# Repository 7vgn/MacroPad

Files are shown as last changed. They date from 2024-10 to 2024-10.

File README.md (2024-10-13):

# MacroPad
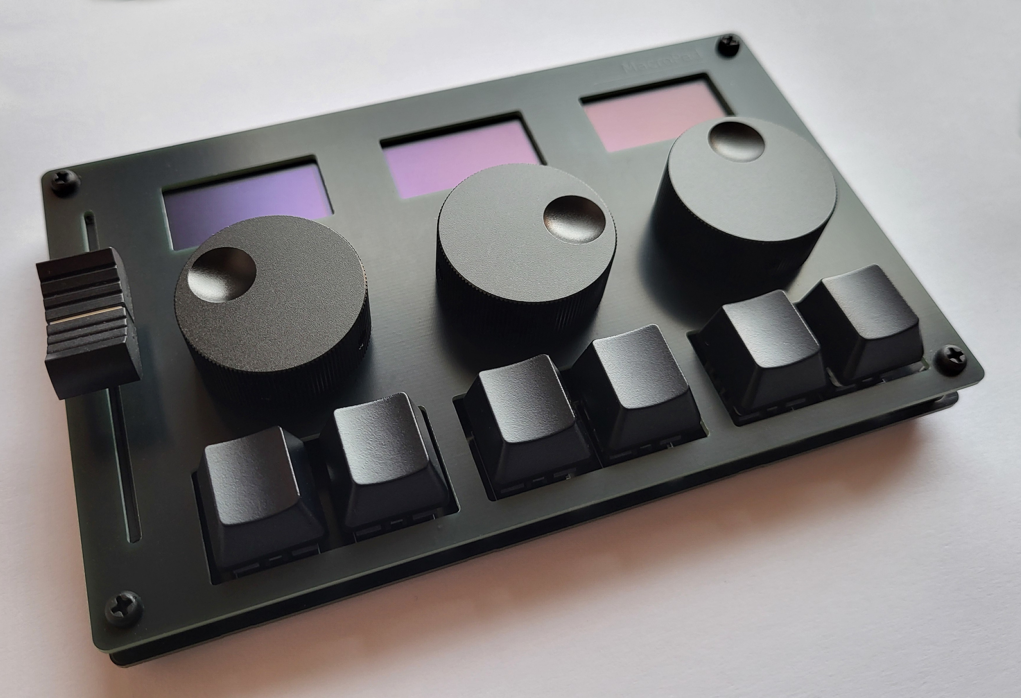
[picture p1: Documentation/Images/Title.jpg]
Title Image

> [!NOTE]
> This project is still under development. While almost everything works on Linux, Windows is a mess.

## What is This?
MacroPad is a USB input device with six keys, three rotary encoders, a slider,
and three OLED displays. All controls can be configured to send user-defined
mouse or keyboard input to the computer. Multiple profiles are supported,
allowing you to change between different key-assignments with the press of a
button. Typical applications include audio and video editing, computer graphics,
and presentations.

MacroPad implements standard USB HID (human interface) device classes and thus
requires no driver. The only is software that is needed is a [Program for
Configuring](Software/) it and potentially some [software for the slider](SliderApps/).

MacroPad is powered by a
[Raspberry Pi Pico](https://www.raspberrypi.com/documentation/microcontrollers/raspberry-pi-pico.html)
using the RP2040 microcontroller.

## How Does It Work?
When plugged into a computer, MacroPad presents itself as a three-in-one
input device composed of a keyboard, a mouse, and a miscellaneous input device.
All keys and rotary encoders can be configured to send keyboard or mouse input
to the computer.

The slider is also an HID-class device that needs no driver. However, most
operating systems don't know what to do with slider input and so they just
ignore it. For that reason, you will most likely want to have a piece of
software running that consumes these inputs and performs certain actions,
like adjusting volume or changing the brush size in a drawing application. 
You can find several examples in the [SliderApps](SliderApps/) folder.

## Can I Have One?
MacroPad is not sold anywhere. In this repository, you can find all the
necessary information and code to build a MacroPad yourself. Please have a look
at the [Building Instructions](Documentation/BuildingInstructions.pdf) and
the [User's Guide](Documentation/UsersGuide.pdf).
Building a MacroPad is not particularly difficult. As long as you can hold a
soldering iron without touching the wrong end, you should be fine.

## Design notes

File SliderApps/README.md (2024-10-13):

The slider on MacroPad acts as a standard USB HID-class slider device and thus needs no driver. However, most operating systems don't know what to do with slider input and therefore just ignore it. For the slider to have any effect, you will need some application running on the host. 

This directory contains two small libraries - one for C++ and one for Python - that can be used to write such applications. Both libraries need the [https://github.com/libusb/hidapi](HIDAPI library) to be installed. 
- The C++ library consists of the MacroPad.h and MacroPad.cpp files. An example for how to use it is in example.cpp. 
- The Python library consists of the MacroPad.py file. An example for how to use it is in example.py. The [cffi](https://cffi.readthedocs.io/) module must be installed. 

In the subdirectories you can find more practical applications for these libraries.

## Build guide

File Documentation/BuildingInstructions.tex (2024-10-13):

\documentclass{article}
\usepackage[a4paper]{geometry}
\usepackage[skip=10pt]{parskip}
\usepackage{amssymb}
\usepackage{graphicx}
\usepackage{hyperref}
\usepackage[section]{placeins}
\usepackage[official]{eurosym}
\usepackage{textgreek}
\usepackage{tcolorbox}
\usepackage{listings}
\usepackage{textcomp}
\usepackage{ccicons}
\usepackage{tikz}
\usepackage{multirow}
\usepackage{longtable}
\usepackage{wasysym}
\usepackage{nicefrac}
\usepackage{pdflscape}

\renewcommand{\familydefault}{\sfdefault}

\setlength\parindent{0pt}

\newenvironment{note}{\begin{tcolorbox}[colback=blue!5!white,colframe=blue!75!black,title=\textbf{Note}]}{\end{tcolorbox}}
\newenvironment{caution}{\begin{tcolorbox}[colback=red!5!white,colframe=red!75!black,title=\textbf{Caution}]}{\end{tcolorbox}}
\newcommand{\file}[1]{\texttt{#1}}

\lstset
{
	basicstyle=\footnotesize\ttfamily,
	breaklines=true,
	keywordstyle=\bfseries\color{green!40!black},
	commentstyle=\itshape\color{purple!40!black},
	identifierstyle=\color{blue},
	stringstyle=\color{orange},
	tabsize=4
}

\begin{document}
\hypersetup{pageanchor=false}
\begin{titlepage}
\thispagestyle{empty}
\centering
\textsf{\Huge MacroPad}\\[1cm]
\textsf{\Large Programmable USB Input Device}\\[3cm]
\\[3cm]
\textsf{\Large Building Instructions}
\end{titlepage}
\hypersetup{pageanchor=true}

\section*{License}
This document is licensed under Creative Commons \href{https://creativecommons.org/licenses/by-nc/4.0/}{Attribution-NonCommercial 4.0 International} (CC BY-NC 4.0 \ccCopy\,\ccAttribution\,\ccNonCommercial).

Attribution to \href{http://github.com/7vgn/MacroPad/}{http://github.com/7vgn/MacroPad/} is sufficient.

\tableofcontents

\section{Introduction}

\subsection{Cloning the GitHub Repository}\label{sec:gitclone}
The very first thing you should do is download (``clone'') the MacroPad GitHub repository to your computer. In order to do so, you first need to \href{https://git-scm.com/downloads}{install Git}.

Once installed, open a command prompt, navigate to the directory you want to download into, then run:
\begin{lstlisting}[language=bash]
git clone --recurse-submodules https://github.com/7vgn/MacroPad.git
\end{lstlisting}
This creates a subdirectory named \file{MacroPad} containing everything you need, including this document.
Downloading might take a few minutes since the \lstinline[language=bash]{--recurse-submodules} option also downloads other required libraries that are included as submodules. 

\subsection{How Much Does It Cost to Build One?}
Prices vary a lot over time and across countries, therefore we can't give a fixed number.
As an example, in mid 2024 in Western Europe, we were able to get the PCBs for approximately 40\euro{} and the other components for around 30\euro{}. However, this included five copies of each PCB (the minimum amount that could be ordered from the manufacturer), so the price per unit drops significantly if you build more than one.

Some components like the resistors, capacitors, slide potentiometer, and EEPROM can quite possibly be salvaged from old electronics.
You don't need the exact \textOmega{} or nF values. Anything in the rough ballpark should work just as well.

\section{Making the Hardware}
If you've never worked with electronics, building your own USB device might seem daunting. But it's actually really not that hard and we encourage you to do it! This chapter contains all the information you need. 

\subsection{Things You Need}
\subsubsection{Tools}
When it comes to tools, you need a soldering iron, pincers, wire cutters, and a well-lit and ventilated workspace. We also recommend a multimeter for testing your solder joints. 
None of these have to be of particularly high quality, normal hobbyist workshop-type tools will do. 

In terms of materials, you need some lead-free solder wire, solder wick, flux, and isopropyl alcohol for cleaning. You can make flux yourself by dissolving some \href{https://en.wikipedia.org/wiki/Rosin}{rosin} flakes in isopropyl alcohol. A clean empty nailpolish remover bottle is ideal for this, as they usually come with a small brush in the lid. 

\subsubsection{Printed Circuit Boards (PCBs)}
The main structure of MacroPad is made from two Printed Circuit Boards (PCBs). The bottom PCB carries all the electrical functions, the top just serves as the front plate. While it is easiest to have them both maufactured together, you can replace the top PCB with a 3D-printed or laser-cut front plate. 

The PCBs were designed using Version 8 of \href{https://www.kicad.org/}{KiCAD}. Once you have downloaded and installed the program, you can open the project from the \file{PCB} subdirectory. 

Find a manufacturer for your PCBs. Producing single digit quantities of PCBs is typically referred to as ``prototyping''. The most affordable PCB prototyping services are usually located in China and take up to two week for shipping. 
When shopping for PCB manufacturing services, use the following parameters:
\begin{itemize}
\item Size: 160mm by 100mm
\item Layers: 2 (there are copper traces on the front and back)
\item Thickness: 1.6mm (this is the standard thickness for PCBs)
\item Surface finish: any lead-free option (HASL is usually the cheapest)
\item Color: up to you (we use black)
\item Customer reference/order number: Manufacturers often print a reference number on the PCBs. While this is fine on the back PCB, you probably don't want that on the front plate. Most manufacturers allow omitting the number (for a fee) or printing it at a position chosen by the customer (e.g. on the back side or under the knobs). Choosing the position is sometimes done on the ordering page. Other times, you have to place a dummy label in KiCAD which the manufacturer will replace with the number. 
\end{itemize}

PCB manufacturers want the data in the shape of so-called `Gerber Files''. Gerbers are to PCBs what PDFs are to text documents. When exporting Gerbers from KiCAD, there are some options to choose. Virtually all manufacturers list those on their website. Most of the time they will provide detailed instructions and screenshots for all popular CAD programs, including KiCAD. 

As an example, here is how you would order from JLCPBC. This is just an example, we are not endorsing them or any other manufacturer! 

After loading the project in KiCAD, open \file{MacroPad.kicad\_pcb}. 

A Google search for ``jlcpcb kicad'' will guide you to \href{https://jlcpcb.com/help/article/how-to-generate-gerber-and-drill-files-in-kicad-8}{this page} with a detailed tutorial. Follow the steps, then compress the resulting files into a ZIP file. 

For the front plate, open the \file{MacroPad\_FrontPlate.kicad\_pcb} file in the PCB Editor. Before we export Gerbers, we need to add a text label for the reference number. Select the ``B.Silkscreen'' layer and place a text label with the word "JLCJLCJLCJLC" somewhere on the PCB. Make the text width and height at least 1mm and the thickness at least 0.153mm (this is the minimum font size allowed by JLCPCB). Now proceeed with the export process as before. 

Go to the JLCPCB homepage and upload the first ZIP file. The website should recognise most of the settings automatically. There are only some minor changes you need to make:
\begin{itemize}
\item Select the PCB color (the default is green)
\item Choose ``LeadFree HASL'' for the Surface Finish (ENIG works too, but is much more expensive)
\item (For the Front PCB) Under ``Mark on PCB'' select ``Order Number (Specify Position)'' (clicking the question mark icon will explain why we placed the text label earlier)
\end{itemize}

Put the PCB in the shopping cart, then repeat the process for the second ZIP file. Ultimately, it should look something like Figure \ref{fig:pcb_ordering_example}. 

\begin{figure}[htb]
\centering
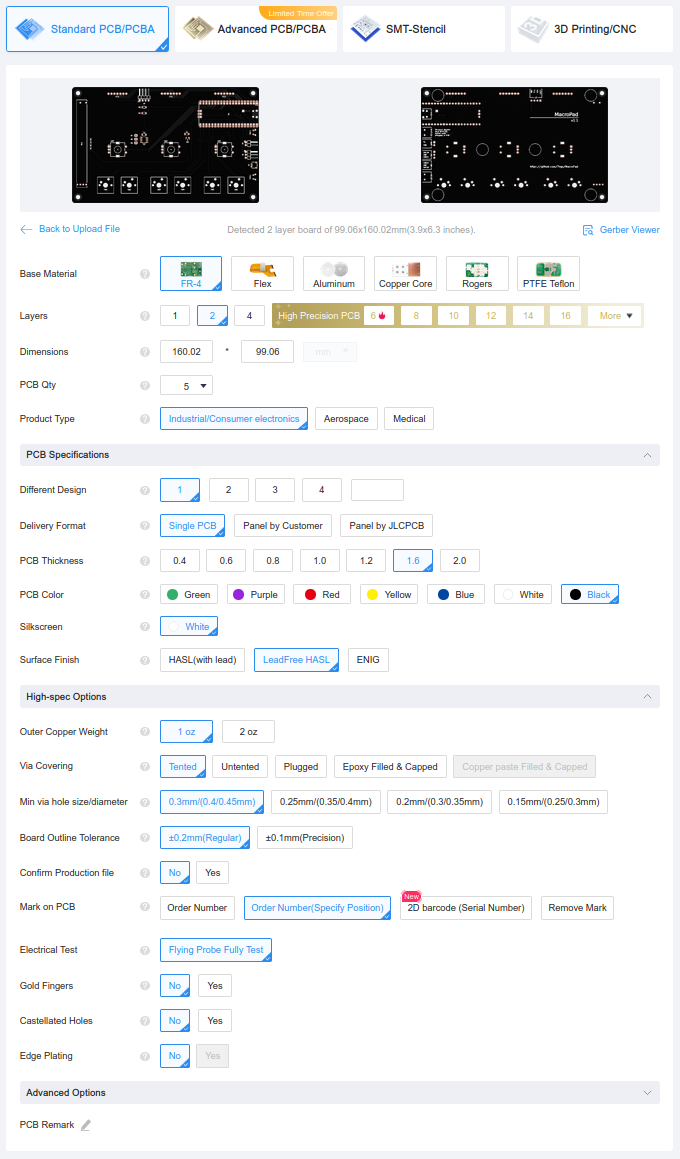
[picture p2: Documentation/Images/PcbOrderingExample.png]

\caption{Example for Ordering PCBs}
\label{fig:pcb_ordering_example}
\end{figure}

\subsubsection{Electronic (and Other) Components}
Figure \ref{fig:bom} is the Bill of Materials (BOM).
It contains product codes for a popular European, American, and Chinese retailer each. Again, this is just to give you an example and does not constitute an endorsement of those sellers. There are myriads of alternatives, many of which might be cheaper or have better availability in your country.

\begin{landscape}
\begin{figure}[htb]
\centering
\begin{longtable}{|l|l|l|c|l|l|l|}\hline
\textbf{Ref}&\textbf{Component}&\textbf{Value}&\textbf{Qty}&\textbf{reichelt.de}&\textbf{mouser.com}&\textbf{AliExpress}\cr\hline\hline
\multicolumn{7}{|c|}{\emph{Necessary Components}}\cr\hline
C2&Ceramic Capacitor&1206, 100nF&1&WAL 1206B104K500&GRM033Z71C104KE14D&\cr\hline
DS1..3&OLED Display&1.3'', SPI (7-pin), SH1106&3&&&\href{https://www.aliexpress.com/item/1005006127524245.html}{Link}\cr\hline
R1,R2&Resistor&1206, 4.7k\textOmega, $\nicefrac{1}{4}$W&2&WAL WR12X4701FTL&279-CRG1206F4K7/10&\cr\hline
\multirow{2}{*}{RV1}&Slide potentiometer&Stereo, linear, 75mm, 10k\textOmega&1&RS60112-LIN10K&688-RS60112A600N&\cr\cline{2-7}
&Knob&&1&KNOPF 4X1,2SW&&\cr\hline
\multirow{2}{*}{SW1..6}&Mechanical switch&Cherry MX Brown&6&CHERRY MX1A-G1NW&540-MX1A-G1NW&\href{https://www.aliexpress.com/item/1005005448524292.html}{Link}\cr\cline{2-7}
&Key caps&For Cherry MX, black&6&&&\href{https://www.aliexpress.com/item/1005006790237962.html}{Link}\cr\hline
\multirow{2}{*}{SW7..9}&Rotary Encoder&15mm shaft length, D-type&3&STEC12E08&858-EN11-VSM1AF15&\href{https://www.aliexpress.com/item/1005005983134515.html}{Link}\cr\cline{2-7}
&Knob&32mm, aluminium, black&3&&&\href{https://www.aliexpress.com/item/1005002272457890.html}{Link}\cr\hline
SW10&Micro switch&2x4x3.5mm, right angle&1&&&\href{https://www.aliexpress.com/item/32873390410.html}{Link}\cr\hline
U1&Raspberry Pi Pico&&1&RASP PI PICO&358-SC0915&\href{https://www.aliexpress.com/item/1005006800440665.html}{Link}\cr\hline
U2&EEPROM&24C512, 64kByte, SOP-8&1&&556-AT24C512C-SSHM-B&\cr\hline
&Rubber/Silicone Feet&Adhesive, $\diameter$11mm $\times$ 5mm&4..6&3M SJ5003 BLACK&517-SJ-5003BK&\href{https://www.aliexpress.com/item/1005005994012506.html}{Link}\cr\hline
&Stand-offs&Male/female, M3, 8mm, black&4&VT DA 8MM&710-971080365&\multirow{2}{*}{\href{https://www.aliexpress.com/item/1005006422618943.html}{Link}}\cr\cline{1-6}
&Bolts and nuts&M3, black&4&&&\cr\hline
&USB cable&Micro or type C, depending on U1&1&&&\cr\hline
\hline\multicolumn{7}{|c|}{\emph{Optional Components}}\cr\hline
C1&Ceramic Capacitor&1206, 100nF&1&WAL 1206B104K500&GRM033Z71C104KE14D&\cr\hline
J1&Pin Header&2.54mm, 1 row, 3 pins&1&SL 1X40W 2,54&538-22-28-6030&\cr\hline
J2&Connector&JST SH SM03B-SRSS-TB&1&&306-SM03BSRSSTBLFSNP&\href{https://de.aliexpress.com/item/1005006027334406.html}{Link}\cr\hline
J3&Pin Header&2.54mm, 1 row, 2 pins&1&SL 1X40W 2,54&538-22-28-6021&\cr\hline
J4&Pin Header&2.54mm, 1 row, 4 pins&1&SL 1X40W 2,54&538-22-28-6040&\cr\hline
SW11&Micro switch&2x4x3.5mm, right angle&1&&&\href{https://www.aliexpress.com/item/32873390410.html}{Link}\cr\hline
U3&Voltage reference&LM4040, 3.0V, SOT-23&1&LM 4040 CIM3-3.0&926-LM4040CIM330NOPB&\cr\hline
\end{longtable}
\caption{Bill of Materials}
\label{fig:bom}
\end{figure}
\end{landscape}

\paragraph{Necessary Components}
The OLED displays don't have a real name or product number but you'll find plenty of them for cheap on marketplaces like eBay or AliExpress. Make sure to get the SPI variant (7 pins) and not the I²C variant (4 pins).

The slide potentiometer is stereo (i.e.\ two mechanically connected potentiometers in one, typically used in audio devices) even though we're only using one. We found that the stereo ones are more widely available and often cheaper than the mono variant. We don't recommend buying the potentiometer from less reputable sources since there are massive differences in quality. 

For the Raspberry Pi Pico you can use the original one or a clone with the same form factor. The latter might differ in the quality of the flash memory and the voltage regulator, but the microcontroller itself is always the same RP2040 chip.\\
The one big advantage of clones is that they are available with a USB-C connector, whereas the original Pico only comes with Micro USB.\\
Other than some issues when flashing via SWD (see Section \ref{sec:fwflash}) -- which you don't need to do -- you won't notice any difference between the two.

\paragraph{Optional Components}
U3 and C1 can be used to stabilize the reference voltage for the Pico's analogue-to-digital converter (ADC) which reads the slide potentiometer.
Under normal circumstances this shouldn't be necessary. Note that the LM4040 will require approximately 1.5mA all the time which might violate the USB suspend current limit.

J1..4 and SW11 are useful if you want to work on the firmware but they are not required for normal operation.
J3 is a UART connector where the Pico prints debug messages.
J1 is an SWD connector for easier flashing and debugging. J2 is an alternative to J1 for use with the Raspberry Pi Debug Probe.
J4 is an I²C connector where you can monitor the traffic between the Pico and the EEPROM (or connect other I²C devices).
SW11 is the Pico's reset button.

\subsection{Soldering}
Through-hole components are the easiest to solder: just stick them into the PCB, then solder them in from the back. Make sure the soldering iron heats both the component's leg and the PCB's pad. If the solder doesn't stick to both, apply some flux. 

Surface-mount components are slightly more difficult, mostly due to their size. First, apply some flux to the pads. Heat one pad and apply a small amount of solder. Then, while heating the solder on the pad with one hand, slider the component into its place with the other. At this time, the solder joint doesn't have to be nice, its only purpose is to hold the component in its correct place. Once you've achieved that, solder the other pad(s). After that, you can re-do the first solder joint if necessary. 
If the solder bridges adjacent pins, add some flux and reheat them. If this doesn't fix it, use wick to remove surplus solder. 

The recommended order for soldering is first the small components (R1, R2, C2, U2, SW10), then the Pi Pico (U1), then the rotary encoders, switches, and slider (SW1..9, RV1). 

Make sure the EEPROM (U2) is in the correct orientation. The chip has a small indent in one corner which has to align with the marking on the PCB.\\
Try to position the Pi Pico (U1) as precisely as possible. It is important that the test pad on the back line up with the through-hole in the PCB (this connects the BOOTSEL button). Put a small amount of solder in the hole to connect it. 

After that, check all connection using the continuity test mode of your multimeter. Once the displays are soldered, many solder joints become inaccessible. 

Insert the displays loosely. Mount the front plate and turn the device upside down. Shake gently so that the displays come to lie flush against the front plate, then solder them in from the back side. 

Figure \ref{fig:assembly} shows the finished PCB. 

\begin{figure}[htb]
\centering
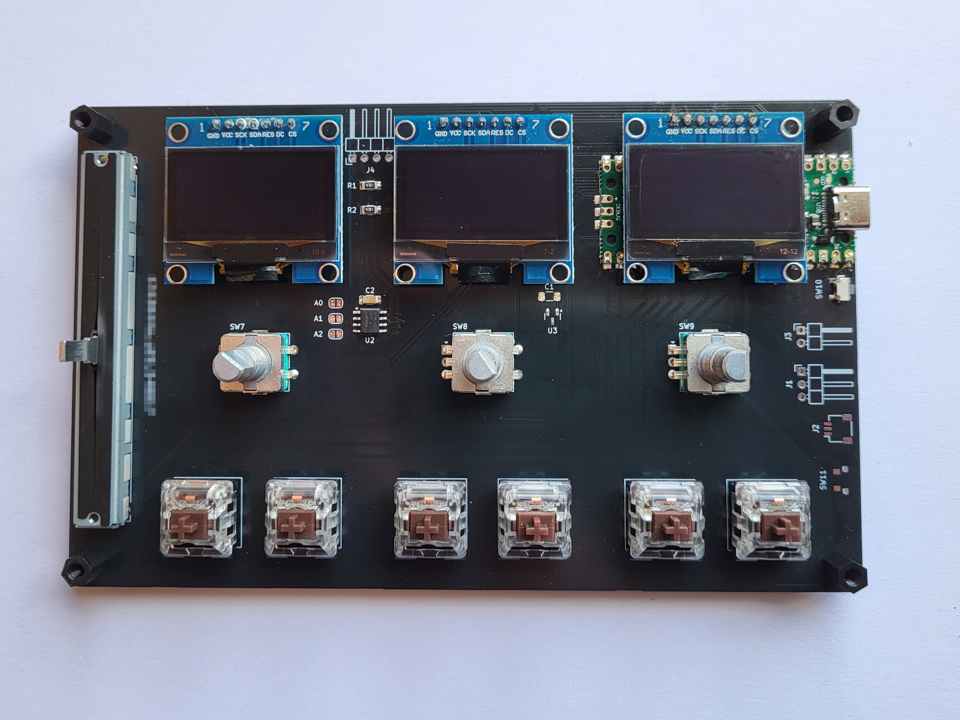
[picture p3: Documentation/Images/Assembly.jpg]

\caption{Assembly of the Back PCB}
\label{fig:assembly}
\end{figure}

Finally, put on the keycaps and knobs. When mounting the knobs onto the rotary encoders, make sure they can be pressed without touching the front plate. 

\section{Firmware}
The firmware is the code that runs on MacroPad's Raspberry Pi Pico microcontroller.

\subsection{Building the Firmware}\label{sec:fwcompile}
\begin{note}
This section is only relevant if you want to compile the firmware yourself from source code.
Otherwise you can just use the finished firmware file (\file{MacroPad.uf2}) from the GitHub repository.
\end{note}

You need to have the following tools and libraries installed:
\begin{itemize}
\item Git: You have already installed this in Section \ref{sec:gitclone}.
\item CMake: The build system used for compiling everything in this repository.
\item C++ Toolchain: Cross compiler and related tools.
\item (Optional) Doxygen: Create documentation for all the classes and functions.
\end{itemize}

If you are on a Debian-based Linux (e.g.\ Ubuntu), you can just install everything with the following command:
\begin{lstlisting}[language=bash]
sudo apt-get install git cmake gcc-arm-none-eabi libnewlib-arm-none-eabi build-essential g++ libstdc++-arm-none-eabi-newlib doxygen
\end{lstlisting}

Open a terminal and change into the \file{Firmware} subdirectory of the downloaded repository. Create a folder named build and change into it:
\begin{lstlisting}[language=bash]
mkdir build
cd build
\end{lstlisting}
Run CMake, then make:
\begin{lstlisting}[language=bash]
cmake ..
make
\end{lstlisting}
After that, you can find the MacroPad.uf2 firmware file inside the build folder.

\subsection{Flashing the Firmware}\label{sec:fwflash}
This section explains how to flash the compiled firmware onto the device via SWD using the \href{https://www.raspberrypi.com/documentation/microcontrollers/debug-probe.html}{Raspberry Pi Debug Probe}.

\begin{note}
Unless you need to flash very often (e.g.\ during debugging), USB is the easier way to go.
Please refer to the User's Guide for how to flash the firmware onto the device via USB.
\end{note}

\subsubsection{Connecting the Debug Probe}
On the Debug Probe, use the connector labelled ``D''. The probe comes with a JST-to-JST as well as a JST-to-female cable. You can use either, depending on which one of connectors J1 and J2 you've soldered. In case of J1, the orange wire goes into SWCLK, the black wire into GND, and the yellow wire into SWDIO.

If you're connecting via J2, you can use the JST-to-female cable instead to hook up MacroPad's UART debug output to the probe's ``U'' connector. The black wire goes to GND and the yellow wire to TX.
The UART settings are 115200 baud, 8N1, and flow control enabled. 

\subsubsection{OpenOCD}
Download and install \href{https://openocd.org/}{OpenOCD} from the website or via your system's package manager. 

The command for flashing is included in the \file{CMakeLists.txt} file. All you need to do is run \lstinline[language=bash]{make flash} from the \file{build} directory. 

\begin{note}
For some reason, OpenOCD does not fully reset both cores of the Pico after flashing. You have to manually press the reset button or disconnect and reconnect the USB cable.
\end{note}

\subsubsection{Pi Pico Clones with Different Flash Chips}
Many clones of the Pi Pico come with different (probably cheaper) on-board flash chips than the original.
While OpenOCD is usually capable of flashing onto these chips, it uses an internal white list which your flash might not be on.
In this case, you will see an error that looks something like this:
\begin{lstlisting}[language=bash]
Error: Unknown flash device (ID 0x00184068)
\end{lstlisting}

Note down the ID from the error message, then perform the following steps to create a patched version of OpenOCD\footnote{Thanks to \href{https://forums.raspberrypi.com/viewtopic.php?t=359245}{this forum thread} for the idea.}:
\begin{enumerate}
\item Uninstall a previously installed OpenOCD.
\item Download the code from the OpenOCD GitHub repository, then change into the directory:
\begin{lstlisting}[language=bash]
git clone https://github.com/raspberrypi/openocd.git --branch rp2040-v0.12.0 --depth=1
cd openocd
\end{lstlisting}
\item Edit src/flash/nor/spi.c and add an entry to the \lstinline[language=C]{flash_devices[]} array, for example:
\begin{lstlisting}[language=C]
FLASH_ID("Unknown", 0x03, 0xeb, 0x02, 0xd8, 0xc7, 0x00184068, 0x100, 0x10000, 0x1000000),
\end{lstlisting}
Most of the values you can just copy from existing entries, but two are important:
In the seventh column, enter the device ID that you noted down earlier.
In the last column, enter the flash size in bytes (e.g.\ 16 megabytes is $2^{24}$ bytes which is 0x1000000 in hexadecimal).
\item Compile and install the modified OpenOCD:
\begin{lstlisting}[language=bash]
./bootstrap
./configure
make
sudo make install
\end{lstlisting}
\end{enumerate}

\iffalse
# How to create the new entry:
# This forum post mentions the technique and gives an exampe for a specific (but
# different) flash chip: https://forums.raspberrypi.com/viewtopic.php?t=359245
# FLASH_ID("pu p32q32", 0x03, 0xeb, 0x02, 0xd8, 0xc7, 0x00156085, 0x100, 0x10000, 0x400000),
#
# The RP2040 datasheet puts pretty strict limits on the kinds of flash chips it
# can use as program memory. This suggests that the parameters should be pretty
# much the same as those of supported chips that are found on the original Pico.
# So far, taking the entry above and only changing the device id (7th column)
# and the size in bytes (last column) has worked.
\fi

\section{Settings App}
MacroPad comes with an application that allows you to change the settings. This application is available for Linux and Windows. You can download it from the GitHub repository.

\begin{note}
The app will probably also compile for Mac, but this has not been tested.
\end{note}

It is also possible to compile the app yourself from source code. Two libraries are required: \href{https://github.com/libusb/hidapi}{HIDAPI} (for communication via USB) and \href{https://www.wxwidgets.org/}{wxWidgets} (for the graphical user interface). You also need CMake and a C++ compiler, both of which you have already install in Section \ref{sec:fwcompile}. 

\subsection{Building on Linux}
Install the necessary libraries:
\begin{lstlisting}[language=bash]
sudo apt-get install libwsgtk3.2-dev libhidapi-dev
\end{lstlisting}

In a terminal, go to the \file{Software} subdirectory of the downloaded repository, then run: 
\begin{lstlisting}[language=bash]
mkdir build
cd build
cmake ..
make
\end{lstlisting}

After that, you will find the executables called \file{MacroPad} and \file{macropad-cli} in the \file{build} directory. 

\subsection{Building on Windows}
TODO

\section{Miscellaneous}
\subsection{USB Vendor ID and Product ID}
USB devices need a Vendor ID (VID) and Product ID (PID) to be identified by the host. VIDs and PIDs are 4-digit hexadecimal numbers. Commercial manufacturers licence their VID from the \href{https://www.usb.org/getting-vendor-id}{USB Implementers Forum (USB-IF)}.
As a hobbyist project, MacroPad does not have a VID or PID. However, for private use, no one prevents you from just using a made-up VID/PID combination (ideally one that is not used by another device).
You can specify the VID/PID in the usb\_descriptors.h file. After doing so, you need to recompile both the firmware and the Settings App.

\subsection{Key Rollover}
Key rollover describes the ability of a keyboard to register (and report to the host) multiple keys being held down at the same time. Pretty much all USB keyboards support at least 6-key rollover (6KRO). Higher-end ones even allow arbitrarily high $n$-key rollover (NKRO). Modifier keys (shift, control, alt, windows) typically do not count towards the KRO number.

There is a common misconception that USB keyboards are limited to 6KRO. This is false, albeit with a kernel of truth: USB HID\footnote{Human Interface Device}-class devices send data to the host (the computer) at regular intervals in data packages called ``reports''. The format of these reports (and as a consequence the maximum possible number of concurrently pressed keys) is not fixed. Instead, each device specifies the exact format via a ``report descriptor''. While this allows for incredible flexibility, it also makes HID drivers on the host side (those usually come with the operating system) quite complex: The driver has to read the report descriptor and from it generate a bespoke parser for each device. Not all systems have the ressources to do that. In particular, older BIOSes tend not to implement a full USB HID driver. For this reason, a special type of USB HID device was defined. These so called ``boot-protocol keyboards'' have a fixed report descriptor which only allows 6KRO.

On the hardware level, MacroPad has no limitations regarding key rollover. All input controls are wired separately to the microcontroller, thanks to the relatively low number of switches and knobs. There is no matrix involved which makes eliminates any kind of ghosting.

On the software side, things become more interesting. Keep in mind that MacroPad is not a standard keyboard where each switch corresponds to one key being sent to the host. Instead, all input controls are freely programmable. In theory, you could configure a switch to act as if the whole alphabet had been pressed. In other words, the number of physical keys has nothing to do with how many keys are reported to the host.
MacroPad is capable of emulating a boot-protocol keyboard (with 6KRO) but it can also use the normal report protocol, in which case it has 16KRO by default. It is the host that chooses which protocol to use.

While the boot protocol's 6KRO is fixed, the 16KRO can be changed if you need higher rollover: When compiling the firmware, you can pass a flag setting a specific KRO value, for example:
\begin{lstlisting}[language=bash]
cmake -DKRO=20 ..
\end{lstlisting}
Note that higher values result in longer reports, eating more of the USB connection's bandwidth. Do not go beyond 60 otherwise you risk exceeding the size of a USB package. 

\end{document}

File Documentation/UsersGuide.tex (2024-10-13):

\documentclass{article}
\usepackage[a4paper]{geometry}
\usepackage[skip=10pt]{parskip}
\usepackage{amssymb}
\usepackage{graphicx}
\usepackage{hyperref}
\usepackage[section]{placeins}
\usepackage[official]{eurosym}
\usepackage{textgreek}
\usepackage{tcolorbox}
\usepackage{listings}
\usepackage{textcomp}
\usepackage{ccicons}
\usepackage{tikz}

\renewcommand{\familydefault}{\sfdefault}

\setlength\parindent{0pt}

\newenvironment{note}{\begin{tcolorbox}[colback=blue!5!white,colframe=blue!75!black,title=\textbf{Note}]}{\end{tcolorbox}}
\newenvironment{caution}{\begin{tcolorbox}[colback=red!5!white,colframe=red!75!black,title=\textbf{Caution}]}{\end{tcolorbox}}
\newcommand{\file}[1]{\texttt{#1}}

\lstset
{
	basicstyle=\footnotesize\ttfamily,
	breaklines=true,
	keywordstyle=\bfseries\color{green!40!black},
	commentstyle=\itshape\color{purple!40!black},
	identifierstyle=\color{blue},
	stringstyle=\color{orange},
	tabsize=4
}

\begin{document}
\hypersetup{pageanchor=false}
\begin{titlepage}
\thispagestyle{empty}
\centering
\textsf{\Huge MacroPad}\\[1cm]
\textsf{\Large Programmable USB Input Device}\\[3cm]
\\[3cm]
\textsf{\Large User's Guide}
\end{titlepage}
\hypersetup{pageanchor=true}

\section*{License}
This document is licensed under Creative Commons \href{https://creativecommons.org/licenses/by-nc/4.0/}{Attribution-NonCommercial 4.0 International} (CC BY-NC 4.0 \ccCopy\,\ccAttribution\,\ccNonCommercial).

Attribution to \href{http://github.com/7vgn/MacroPad/}{http://github.com/7vgn/MacroPad/} is sufficient.
\tableofcontents

\section{Introduction}
MacroPad is a USB input device with three knobs, one slider, and six keys. It also features three OLED displays to show the current bindings of the input controls. Figure \ref{fig:overview} shows the positions of all the controls.
\begin{figure}[htb]
\centering
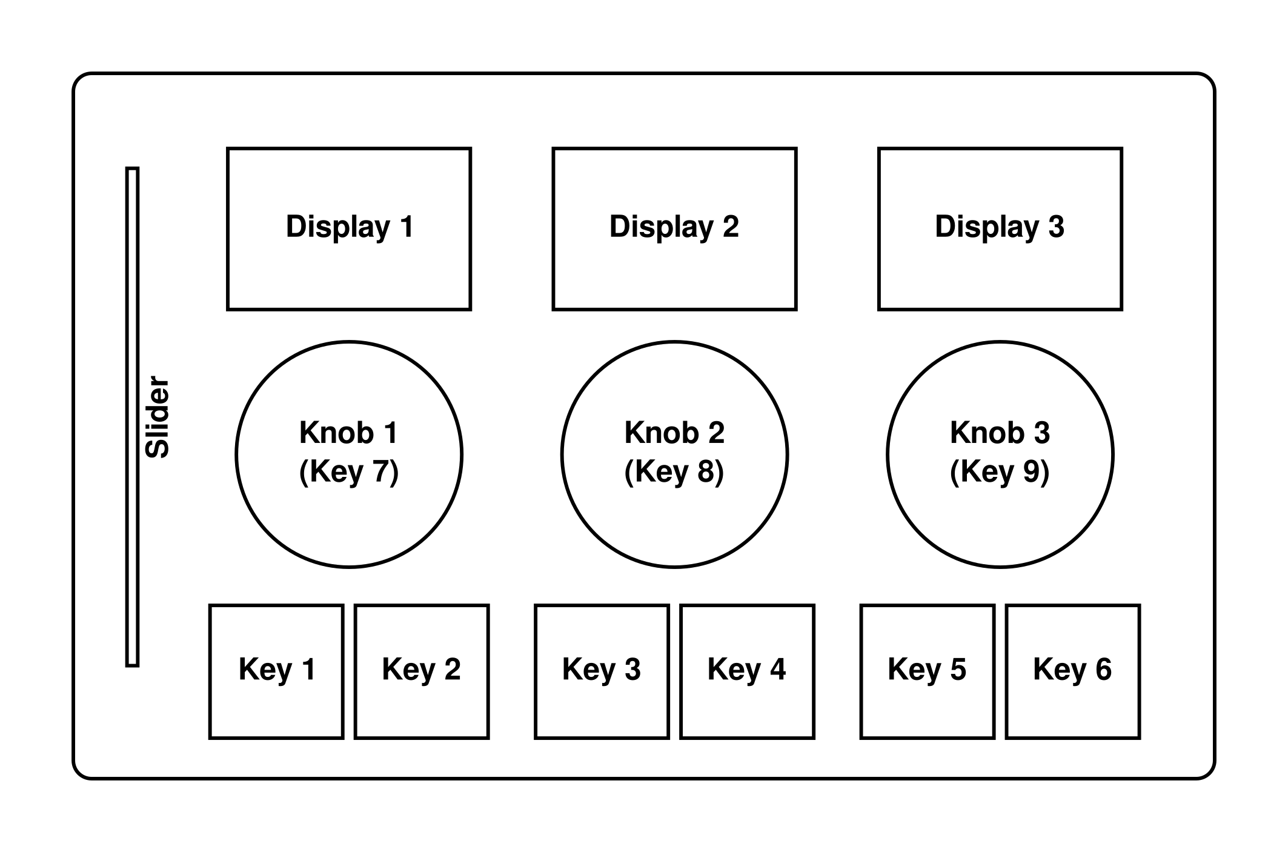
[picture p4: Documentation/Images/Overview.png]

\caption{Overview of the Device}
\label{fig:overview}
\end{figure}

The knobs can not just be turned but also pressed which is why they are also listed as keys.

During normal operation, Display 1 will show the bindings of the input controls below it, that is Keys 1 and 2, as well as Knob 1 (including Key 7). The same goes for the other two displays.

MacroPad presents itself to the computer as a combination of standard USB input devices (a keyboard, a mouse etc.). This means it should work on any operating system without the need for a driver.\\
Additional software might be required if you want it to perform actions that go beyond what keyboard/mouse/etc.\ inputs can do (for example performing actions in specific applications that don't have hotkeys).

\section{Customise MacroPad}\label{sec:customise}
\subsection{How Settings Work: Actions, Macros, and Profiles}\label{sec:settings}
MacroPad supports multiple profiles that you can switch between. The active profile defines what is sent to the computer in reaction to the user interacting with the input controls. Profiles also define the images shown on the displays and a few other things.

Having multiple profiles allows you to reconfigure MacroPad quickly without having to upload new settings. For example, you might want to create different profiles for different applications, although they are not necessarily tied to that. You might have multiple profiles for the same application or simple just one profile for everything.

To understand how a profile maps user inputs to signals sent over USB, we need to define some terms:

An \emph{Action} is a piece of information (e.g.\ ``ctrl key and right mouse button are pressed'') sent to the host over USB. Being a USB HID\footnote{Human Interface Device}-class device, MacroPad sends a report every 10 milliseconds. Such a report contains a list of all the keys and mouse buttons that are currently down, as well as incremental changes (e.g.\ how far has the mouse moved in x direction since the last report). MacroPad combines all current actions (from the different input controls) into a report which it then sends to the host.

A \emph{Macro} is a sequence of actions, with a duration for each action. A macro might for example look like this: Have the left mouse button and the shift key down (first action) for 20ms. Then move the mouse downwards at a rate of five units per 10ms (second action) for 30ms. After that, have the alt and enter keys down (third action) for 10ms.
Executing this macro would take 60ms during which time seven reports would be sent (the seventh report being ``all keys have been released'').

There are two types of user input events: First, we have keys being held down, i.e.\ events that occur over a period of time. Such an event causes an action to be continuously reported as long as the key is down.
The second type of event concerns singular points in time: This includes button presses and releases, as well as rotating a knob one notch to the left or right. These kinds of events trigger macros.

There is no dedicated key for switching between profiles. Instead, profile switching is just a special kind of action. This means you can assign it freely to any key or knob event in each profile. Or not -- if you're only using a single profile -- thus gaining more space for other actions.

\subsection{The MacroPad Settings App}\label{sec:settings_app}
MacroPad comes with an graphical user interface app that allows you to create, modify, and upload settings. You can also store settings in an XML file on your computer.

The Settings App is called \lstinline[language=bash]{MacroPad} (\lstinline[language=bash]{MacroPad.exe} on Windows). There is no installer -- just copy the executable file to some place on your computer and run it.

The Settings App should be pretty self-explanatory. Each profile is configured in a separate tab. In order to change the behaviour of an input control (like a key), click on it, then edit the macro or action. You can create or import custom pictures for each profile, key, and knob.
If you're using multiple profiles, don't forget to configure one of the input controls to switch between them.

If you're overwhelmed by the options, you can load and modify an existing settings file instead.

Once you have created your personalised settings, it is recommended that you save them in a file for safekeeping.
In order to write them to the device, hit the ``Scan for Devices'' button, choose the correct MacroPad device from the drop-down (in case you have multiple), then hit ``Write to Device''. After a few seconds, your MacroPad should have its new settings.
\begin{note}
Do not unplug the device while settings are transferred.
\end{note}

\subsubsection{User priviledges on Linux}\label{sec:linux_priviledges}
On Linux, the app must be run with root proviledges (``sudo'') since normal users are not allowed to access USB devices.

If you don't want that, you can add an exception for MacroPad: The following steps describe how to do this on Debian-based distributions like Ubuntu. On other Linux systems there might be slight differences.
\begin{enumerate}
\item Open a terminal and run \lstinline[language=bash]{lsusb}.
If lsusb is not on your system you can get it by installing the usbutils package:
\begin{lstlisting}[language=bash]
sudo apt-get install usbutils
\end{lstlisting}
Find the line with the MacroPad device and note down the Vendor ID (VID) and Product ID (PID). These are 4-letter/digit codes separated by a colon (VID:PID).\\
\item In a text editor of your choice, create a file named ``69-MacroPad.rules'' with the following content:\\
~\\
\texttt{SUBSYSTEMS=="usb", ATTRS{idVendor}=="VID", ATTRS{idProduct}=="PID", TAG+="uaccess"
KERNEL=="hidraw", ATTRS{idVendor}=="VID", ATTRS{idProduct}=="PID", TAG+="uaccess"}
~\\
Replace ``VID'' and ``PID'' with the IDs noted down before.
\item Copy the file to /etc/udev/rules.d/ (you must use root priviledges to do that):
\begin{lstlisting}[language=bash]
sudo cp 69-MacroPad.rules /etc/udev/rules.d/.
\end{lstlisting}
\item Restart your computer or run the following commands:
\begin{lstlisting}[language=bash]
sudo udevadm control --reload-rules
sudo udevadm trigger
\end{lstlisting}
\end{enumerate}

\subsection{The Command Line Settings Tool}\label{sec:cmdline_tool}
There is a command line-based alternative for the Settings App, called \lstinline[language=bash]{macropad-cli}. It can transfer the same XML settings files from and to MacroPad devices as the graphical Settings App. For more information on how to use the command-line tool, run:
\begin{lstlisting}[language=bash]
macropad-cli --help
\end{lstlisting}
The command-line tool provides no means for creating and editing settings files. For this, you need either the graphical Settings App or edit the XML file by hand.
Unless you have a very particular use case, we recommend you use the graphical Settings App instead.

\section{Firmware Update}\label{sec:firmwareupdate}
\begin{note}
Sections \ref{sec:flash} and \ref{sec:restoresettings} also apply to the initial flashing of the firmware onto an empty device.
\end{note}

\subsection{Save Your Settings}\label{sec:savesettings}
Firmware updates do not preserve the settings. If you want to keep your profiles, read them from the device and store them in a file on your computer before starting the firmware update process. See Section \ref{sec:settings_app} for details.
Make sure to use the old Settings App to do this. The Settings App can only read settings from a device with the same firmware version.

\subsection{Flash the New Firmware}\label{sec:flash}
Download the new firmware. It comes in a file ending in ``.uf2''.
\begin{enumerate}
\item Unplug your device.
\item Locate the ``BOOTSEL'' button. The labels on the back of device can help you find it.
\item Press the button and keep holding it, while plugging the USB cable from your computer into the device.
\item Your computer should recognize it as a mass storage device. On most operating systems, a file manager window will pop up.
\item Release the button.
\item Copy the new firmware file onto the device.
\item The mass storage device will immediately self-eject and MacroPad reappears as several input devices. If it doesn't, unplug and replug the USB cable.
\end{enumerate}

\subsection{Restore Your Settings}\label{sec:restoresettings}
Now you can write your settings back onto the device as described in Section \ref{sec:settings_app}.
Make sure to use the new Settings App to do this. The Settings App can only write settings to a device with the same firmware version.

\end{document}

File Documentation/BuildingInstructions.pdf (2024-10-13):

# MacroPad

## Programmable USB Input Device


## Building Instructions

## License

This document is licensed under Creative Commons Attribution-NonCommercial 4.0 International (https://creativecommons.org/licenses/by-nc/4.0/) (CC BY-NC 4.0 © b n).

Attribution to http://github.com/7vgn/MacroPad/ is sufficient.

## Contents

1 Introduction | 1
2 Making the Hardware | 2
3 Firmware | 7
4 Settings App | 10
5 Miscellaneous | 10

## 1 Introduction

### 1.1 Cloning the GitHub Repository

The very first thing you should do is download (“clone”) the MacroPad GitHub repository to your computer. In order to do so, you first need to install Git. (https://git-scm.com/downloads)

Once installed, open a command prompt, navigate to the directory you want to download into, then run:

git clone --recurse - submodules https :// github . com /7 vgn / MacroPad . git

This creates a subdirectory named MacroPad containing everything you need, including this document. Downloading might take a few minutes since the --recurse-submodules option also downloads other required libraries that are included as submodules.

1

### 1.2 How Much Does It Cost to Build One?

Prices vary a lot over time and across countries, therefore we can’t give a fixed number. As an example, in mid 2024 in Western Europe, we were able to get the PCBs for approximately 40€ and the other components for around 30€. However, this included five copies of each PCB (the minimum amount that could be ordered from the manufacturer), so the price per unit drops significantly if you build more than one.

Some components like the resistors, capacitors, slide potentiometer, and EEPROM can quite possibly be salvaged from old electronics. You don’t need the exact Ω or nF values. Anything in the rough ballpark should work just as well.

## 2 Making the Hardware

If you’ve never worked with electronics, building your own USB device might seem daunting. But it’s actually really not that hard and we encourage you to do it! This chapter contains all the information you need.

### 2.1 Things You Need

### 2.1.1 Tools

When it comes to tools, you need a soldering iron, pincers, wire cutters, and a well-lit and ventilated workspace. We also recommend a multimeter for testing your solder joints. None of these have to be of particularly high quality, normal hobbyist workshop-type tools will do.

In terms of materials, you need some lead-free solder wire, solder wick, flux, and isopropyl alcohol for cleaning. You can make flux yourself by dissolving some rosin (https://en.wikipedia.org/wiki/Rosin) flakes in isopropyl alcohol. A clean empty nailpolish remover bottle is ideal for this, as they usually come with a small brush in the lid.

### 2.1.2 Printed Circuit Boards (PCBs)

The main structure of MacroPad is made from two Printed Circuit Boards (PCBs). The bottom PCB carries all the electrical functions, the top just serves as the front plate. While it is easiest to have them both maufactured together, you can replace the top PCB with a 3D-printed or laser-cut front plate.

The PCBs were designed using Version 8 of KiCAD. (https://www.kicad.org/) Once you have downloaded and installed the program, you can open the project from the PCB subdirectory.

Find a manufacturer for your PCBs. Producing single digit quantities of PCBs is typically referred to as “prototyping”. The most affordable PCB prototyping services are usually located in China and take up to two week for shipping. When shopping for PCB manufacturing services, use the following parameters:

- Size: 160mm by 100mm
- Layers: 2 (there are copper traces on the front and back)
- Thickness: 1.6mm (this is the standard thickness for PCBs)

2

- Surface finish: any lead-free option (HASL is usually the cheapest)
- Color: up to you (we use black)
- Customer reference/order number: Manufacturers often print a reference number on the PCBs. While this is fine on the back PCB, you probably don’t want that on the front plate. Most manufacturers allow omitting the number (for a fee) or printing it at a position chosen by the customer (e.g. on the back side or under the knobs). Choosing the position is sometimes done on the ordering page. Other times, you have to place a dummy label in KiCAD which the manufacturer will replace with the number.

PCB manufacturers want the data in the shape of so-called ‘Gerber Files”. Gerbers are to PCBs what PDFs are to text documents. When exporting Gerbers from KiCAD, there are some options to choose. Virtually all manufacturers list those on their website. Most of the time they will provide detailed instructions and screenshots for all popular CAD programs, including KiCAD.

As an example, here is how you would order from JLCPBC. This is just an example, we are not endorsing them or any other manufacturer!

After loading the project in KiCAD, open MacroPad.kicad pcb.

A Google search for “jlcpcb kicad” will guide you to this page (https://jlcpcb.com/help/article/how-to-generate-gerber-and-drill-files-in-kicad-8) with a detailed tutorial. Follow the steps, then compress the resulting files into a ZIP file.

For the front plate, open the MacroPad FrontPlate.kicad pcb file in the PCB Editor. Before we export Gerbers, we need to add a text label for the reference number. Select the “B.Silkscreen” layer and place a text label with the word ”JLCJLCJLCJLC” somewhere on the PCB. Make the text width and height at least 1mm and the thickness at least 0.153mm (this is the minimum font size allowed by JLCPCB). Now proceeed with the export process as before.

Go to the JLCPCB homepage and upload the first ZIP file. The website should recognise most of the settings automatically. There are only some minor changes you need to make:

- Select the PCB color (the default is green)
- Choose “LeadFree HASL” for the Surface Finish (ENIG works too, but is much more expensive)
- (For the Front PCB) Under “Mark on PCB” select “Order Number (Specify Position)” (clicking the question mark icon will explain why we placed the text label earlier)

Put the PCB in the shopping cart, then repeat the process for the second ZIP file. Ultimately, it should look something like Figure 1.

### 2.1.3 Electronic (and Other) Components

Figure 2 is the Bill of Materials (BOM). It contains product codes for a popular European, American, and Chinese retailer each. Again, this is just to give you an example and does not constitute an endorsement of those sellers. There are myriads of alternatives, many of which might be cheaper or have better availability in your country.

3

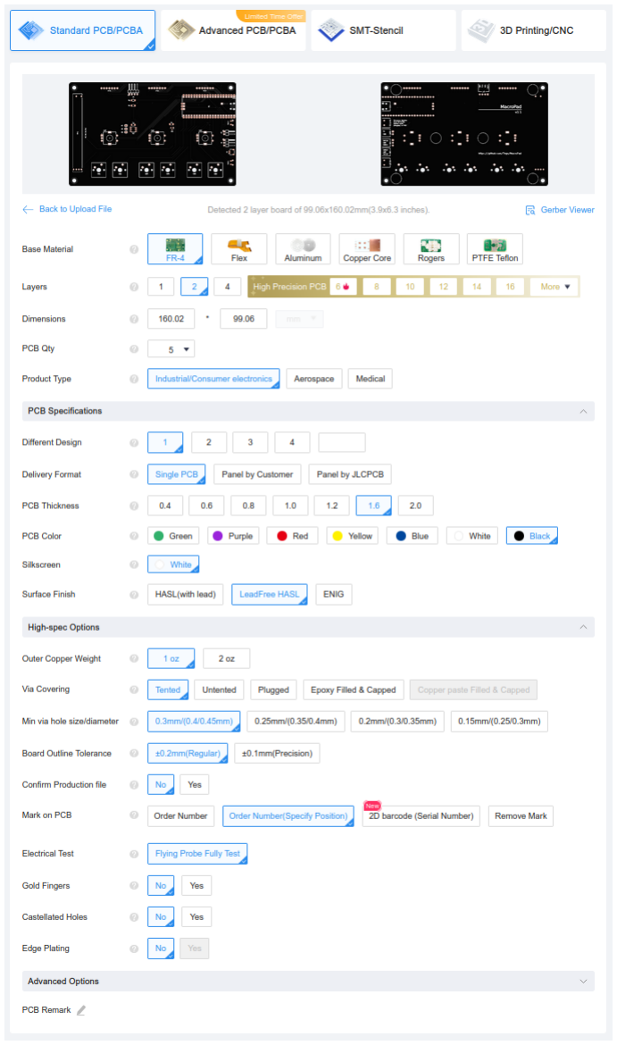
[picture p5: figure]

Figure 1: Example for Ordering PCBs

4

Ref | Component | Value | Qty | reichelt.de | mouser.com | AliExpress
Necessary Components
C2 | Ceramic Capacitor | 1206, 100nF | 1 | WAL 1206B104K500 | GRM033Z71C104KE14D
DS1..3 | OLED Display | 1.3”, SPI (7-pin), SH1106 | 3 | | | Link (https://www.aliexpress.com/item/1005006127524245.html)
R1,R2 | Resistor | 1206, 4.7kΩ, 1/4W | 2 | WAL WR12X4701FTL | 279-CRG1206F4K7/10
RV1 | Slide potentiometer | Stereo, linear, 75mm, 10kΩ | 1 1 | RS60112-LIN10K KNOPF 4X1,2SW | 688-RS60112A600N Knob
SW1..6 | Mechanical switch | Cherry MX Brown For Cherry MX, black | 6 6 | CHERRY MX1A-G1NW | 540-MX1A-G1NW | Link (https://www.aliexpress.com/item/1005005448524292.html) Key caps Link (https://www.aliexpress.com/item/1005006790237962.html)
SW7..9 | Rotary Encoder | 15mm shaft length, D-type 32mm, aluminium, black | 3 3 | STEC12E08 | 858-EN11-VSM1AF15 | Link (https://www.aliexpress.com/item/1005005983134515.html) Knob Link (https://www.aliexpress.com/item/1005002272457890.html)
SW10 | Micro switch | 2x4x3.5mm, right angle | 1 | | | Link (https://www.aliexpress.com/item/32873390410.html)
U1 | Raspberry Pi Pico | | 1 | RASP PI PICO | 358-SC0915 | Link (https://www.aliexpress.com/item/1005006800440665.html)
U2 | EEPROM | 24C512, 64kByte, SOP-8 | 1 | | 556-AT24C512C-SSHM-B
| Rubber/Silicone Feet | Adhesive, 11mm × 5mm | 4..6 | 3M SJ5003 BLACK | 517-SJ-5003BK | Link (https://www.aliexpress.com/item/1005005994012506.html)
Stand-offs | Male/female, M3, 8mm, black M3, black | 4 4 | VT DA 8MM | 710-971080365 | Link (https://www.aliexpress.com/item/1005006422618943.html) Bolts and nuts
USB cable | Micro or type C, depending on U1 | 1
Optional Components
C1 | Ceramic Capacitor | 1206, 100nF | 1 | WAL 1206B104K500 | GRM033Z71C104KE14D
J1 | Pin Header | 2.54mm, 1 row, 3 pins | 1 | SL 1X40W 2,54 | 538-22-28-6030
J2 | Connector | JST SH SM03B-SRSS-TB | 1 | | 306-SM03BSRSSTBLFSNP | Link (https://de.aliexpress.com/item/1005006027334406.html)
J3 | Pin Header | 2.54mm, 1 row, 2 pins | 1 | SL 1X40W 2,54 | 538-22-28-6021
J4 | Pin Header | 2.54mm, 1 row, 4 pins | 1 | SL 1X40W 2,54 | 538-22-28-6040
SW11 | Micro switch | 2x4x3.5mm, right angle | 1 | | | Link (https://www.aliexpress.com/item/32873390410.html)
U3 | Voltage reference | LM4040, 3.0V, SOT-23 | 1 | LM 4040 CIM3-3.0 | 926-LM4040CIM330NOPB

Figure 2: Bill of Materials

5

Necessary Components The OLED displays don’t have a real name or product number but you’ll find plenty of them for cheap on marketplaces like eBay or AliExpress. Make sure to get the SPI variant (7 pins) and not the I²C variant (4 pins).

The slide potentiometer is stereo (i.e. two mechanically connected potentiometers in one, typically used in audio devices) even though we’re only using one. We found that the stereo ones are more widely available and often cheaper than the mono variant. We don’t recommend buying the potentiometer from less reputable sources since there are massive differences in quality.

For the Raspberry Pi Pico you can use the original one or a clone with the same form factor. The latter might differ in the quality of the flash memory and the voltage regulator, but the microcontroller itself is always the same RP2040 chip.
The one big advantage of clones is that they are available with a USB-C connector, whereas the original Pico only comes with Micro USB.
Other than some issues when flashing via SWD (see Section 3.2) – which you don’t need to do – you won’t notice any difference between the two.

Optional Components U3 and C1 can be used to stabilize the reference voltage for the Pico’s analogue-to-digital converter (ADC) which reads the slide potentiometer. Under normal circum-stances this shouldn’t be necessary. Note that the LM4040 will require approximately 1.5mA all the time which might violate the USB suspend current limit.

J1..4 and SW11 are useful if you want to work on the firmware but they are not required for normal operation. J3 is a UART connector where the Pico prints debug messages. J1 is an SWD connector for easier flashing and debugging. J2 is an alternative to J1 for use with the Raspberry Pi Debug Probe. J4 is an I²C connector where you can monitor the traffic between the Pico and the EEPROM (or connect other I²C devices). SW11 is the Pico’s reset button.

### 2.2 Soldering

Through-hole components are the easiest to solder: just stick them into the PCB, then solder them in from the back. Make sure the soldering iron heats both the component’s leg and the PCB’s pad. If the solder doesn’t stick to both, apply some flux.

Surface-mount components are slightly more difficult, mostly due to their size. First, apply some flux to the pads. Heat one pad and apply a small amount of solder. Then, while heating the solder on the pad with one hand, slider the component into its place with the other. At this time, the solder joint doesn’t have to be nice, its only purpose is to hold the component in its correct place. Once you’ve achieved that, solder the other pad(s). After that, you can re-do the first solder joint if necessary. If the solder bridges adjacent pins, add some flux and reheat them. If this doesn’t fix it, use wick to remove surplus solder.

The recommended order for soldering is first the small components (R1, R2, C2, U2, SW10), then the Pi Pico (U1), then the rotary encoders, switches, and slider (SW1..9, RV1).

Make sure the EEPROM (U2) is in the correct orientation. The chip has a small indent in one corner which has to align with the marking on the PCB.
Try to position the Pi Pico (U1) as precisely as possible. It is important that the test pad on the back line up with the through-hole in the PCB (this connects the BOOTSEL button). Put a small amount of solder in the hole to connect it.

6

After that, check all connection using the continuity test mode of your multimeter. Once the displays are soldered, many solder joints become inaccessible.

Insert the displays loosely. Mount the front plate and turn the device upside down. Shake gently so that the displays come to lie flush against the front plate, then solder them in from the back side.

Figure 3 shows the finished PCB.


Figure 3: Assembly of the Back PCB

Finally, put on the keycaps and knobs. When mounting the knobs onto the rotary encoders, make sure they can be pressed without touching the front plate.

## 3 Firmware

The firmware is the code that runs on MacroPad’s Raspberry Pi Pico microcontroller.

7

### 3.1 Building the Firmware

Note

This section is only relevant if you want to compile the firmware yourself from source code. Otherwise you can just use the finished firmware file (MacroPad.uf2) from the GitHub repository.

You need to have the following tools and libraries installed:

- Git: You have already installed this in Section 1.1.
- CMake: The build system used for compiling everything in this repository.
- C++ Toolchain: Cross compiler and related tools.
- (Optional) Doxygen: Create documentation for all the classes and functions.

If you are on a Debian-based Linux (e.g. Ubuntu), you can just install everything with the following command:

sudo apt - get install git cmake gcc -arm -none - eabi libnewlib -arm -none - eabi build -essential g++ libstdc ++ -arm -none -eabi - newlib doxygen

Open a terminal and change into the Firmware subdirectory of the downloaded repository. Create a folder named build and change into it:

mkdir build
cd build

Run CMake, then make:

cmake ..
make

After that, you can find the MacroPad.uf2 firmware file inside the build folder.

### 3.2 Flashing the Firmware

This section explains how to flash the compiled firmware onto the device via SWD using the Raspberry Pi Debug Probe. (https://www.raspberrypi.com/documentation/microcontrollers/debug-probe.html)

Note

Unless you need to flash very often (e.g. during debugging), USB is the easier way to go. Please refer to the User’s Guide for how to flash the firmware onto the device via USB.

### 3.2.1 Connecting the Debug Probe

On the Debug Probe, use the connector labelled “D”. The probe comes with a JST-to-JST as well as a JST-to-female cable. You can use either, depending on which one of connectors J1 and J2 you’ve soldered. In case of J1, the orange wire goes into SWCLK, the black wire into GND, and the yellow wire into SWDIO.

8

If you’re connecting via J2, you can use the JST-to-female cable instead to hook up MacroPad’s UART debug output to the probe’s “U” connector. The black wire goes to GND and the yellow wire to TX. The UART settings are 115200 baud, 8N1, and flow control enabled.

### 3.2.2 OpenOCD

Download and install OpenOCD (https://openocd.org/) from the website or via your system’s package manager.

The command for flashing is included in the CMakeLists.txt file. All you need to do is run make flash from the build directory.

Note

For some reason, OpenOCD does not fully reset both cores of the Pico after flashing. You have to manually press the reset button or disconnect and reconnect the USB cable.

### 3.2.3 Pi Pico Clones with Different Flash Chips

Many clones of the Pi Pico come with different (probably cheaper) on-board flash chips than the original. While OpenOCD is usually capable of flashing onto these chips, it uses an internal white list which your flash might not be on. In this case, you will see an error that looks something like this:

Error : Unknown flash device (ID 0 x00184068 )

Note down the ID from the error message, then perform the following steps to create a patched version of OpenOCD¹
:
1. Uninstall a previously installed OpenOCD.
2. Download the code from the OpenOCD GitHub repository, then change into the directory:

git clone https :// github . com / raspberrypi / openocd . git -- branch rp2040 -v0 .12.0 --depth =1
cd openocd
3. Edit src/flash/nor/spi.c and add an entry to the flash_devices[] array, for example:

FLASH_ID (" Unknown ", 0x03 , 0xeb , 0x02 , 0xd8 , 0xc7 , 0 x00184068 , 0x100 , 0 x10000 , 0 x1000000 ) ,

Most of the values you can just copy from existing entries, but two are important: In the seventh column, enter the device ID that you noted down earlier. In the last column, enter the flash size in bytes (e.g. 16 megabytes is 2

24 bytes which is 0x1000000 in hexadecimal).

4. Compile and install the modified OpenOCD:

./ bootstrap
./ configure
make
sudo make install

1Thanks to this forum thread (https://forums.raspberrypi.com/viewtopic.php?t=359245) for the idea.

9

## 4 Settings App

MacroPad comes with an application that allows you to change the settings. This application is available for Linux and Windows. You can download it from the GitHub repository.

Note

The app will probably also compile for Mac, but this has not been tested.

It is also possible to compile the app yourself from source code. Two libraries are required: HIDAPI (https://github.com/libusb/hidapi) (for communication via USB) and wxWidgets (https://www.wxwidgets.org/) (for the graphical user interface). You also need CMake and a C++ compiler, both of which you have already install in Section 3.1.

### 4.1 Building on Linux

Install the necessary libraries:

sudo apt - get install libwsgtk3 .2 - dev libhidapi - dev

In a terminal, go to the Software subdirectory of the downloaded repository, then run:

mkdir build
cd build
cmake ..
make

After that, you will find the executables called MacroPad and macropad-cli in the build directory.

### 4.2 Building on Windows

TODO

## 5 Miscellaneous

### 5.1 USB Vendor ID and Product ID

USB devices need a Vendor ID (VID) and Product ID (PID) to be identified by the host. VIDs and PIDs are 4-digit hexadecimal numbers. Commercial manufacturers licence their VID from the USB Implementers Forum (USB-IF). (https://www.usb.org/getting-vendor-id) As a hobbyist project, MacroPad does not have a VID or PID. However, for private use, no one prevents you from just using a made-up VID/PID combination (ideally one that is not used by another device). You can specify the VID/PID in the usb descriptors.h file. After doing so, you need to recompile both the firmware and the Settings App.

### 5.2 Key Rollover

Key rollover describes the ability of a keyboard to register (and report to the host) multiple keys being held down at the same time. Pretty much all USB keyboards support at least 6-key rollover (6KRO). Higher-end ones even allow arbitrarily high n-key rollover (NKRO). Modifier keys (shift, control, alt, windows) typically do not count towards the KRO number.

10

There is a common misconception that USB keyboards are limited to 6KRO. This is false, albeit with a kernel of truth: USB HID²
-class devices send data to the host (the computer) at regular intervals in data packages called “reports”. The format of these reports (and as a consequence the maximum possible number of concurrently pressed keys) is not fixed. Instead, each device specifies the exact format via a “report descriptor”. While this allows for incredible flexibility, it also makes HID drivers on the host side (those usually come with the operating system) quite complex: The driver has to read the report descriptor and from it generate a bespoke parser for each device. Not all systems have the ressources to do that. In particular, older BIOSes tend not to implement a full USB HID driver. For this reason, a special type of USB HID device was defined. These so called “boot-protocol keyboards” have a fixed report descriptor which only allows 6KRO.

On the hardware level, MacroPad has no limitations regarding key rollover. All input controls are wired separately to the microcontroller, thanks to the relatively low number of switches and knobs. There is no matrix involved which makes eliminates any kind of ghosting.

On the software side, things become more interesting. Keep in mind that MacroPad is not a standard keyboard where each switch corresponds to one key being sent to the host. Instead, all input controls are freely programmable. In theory, you could configure a switch to act as if the whole alphabet had been pressed. In other words, the number of physical keys has nothing to do with how many keys are reported to the host. MacroPad is capable of emulating a boot-protocol keyboard (with 6KRO) but it can also use the normal report protocol, in which case it has 16KRO by default. It is the host that chooses which protocol to use.

While the boot protocol’s 6KRO is fixed, the 16KRO can be changed if you need higher rollover: When compiling the firmware, you can pass a flag setting a specific KRO value, for example:

cmake -DKRO =20 ..

Note that higher values result in longer reports, eating more of the USB connection’s bandwidth. Do not go beyond 60 otherwise you risk exceeding the size of a USB package.

2Human Interface Device

11

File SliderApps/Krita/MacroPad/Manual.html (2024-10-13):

This Plug-in allows Krita's brush size to be controlled by the MacroPad slider.

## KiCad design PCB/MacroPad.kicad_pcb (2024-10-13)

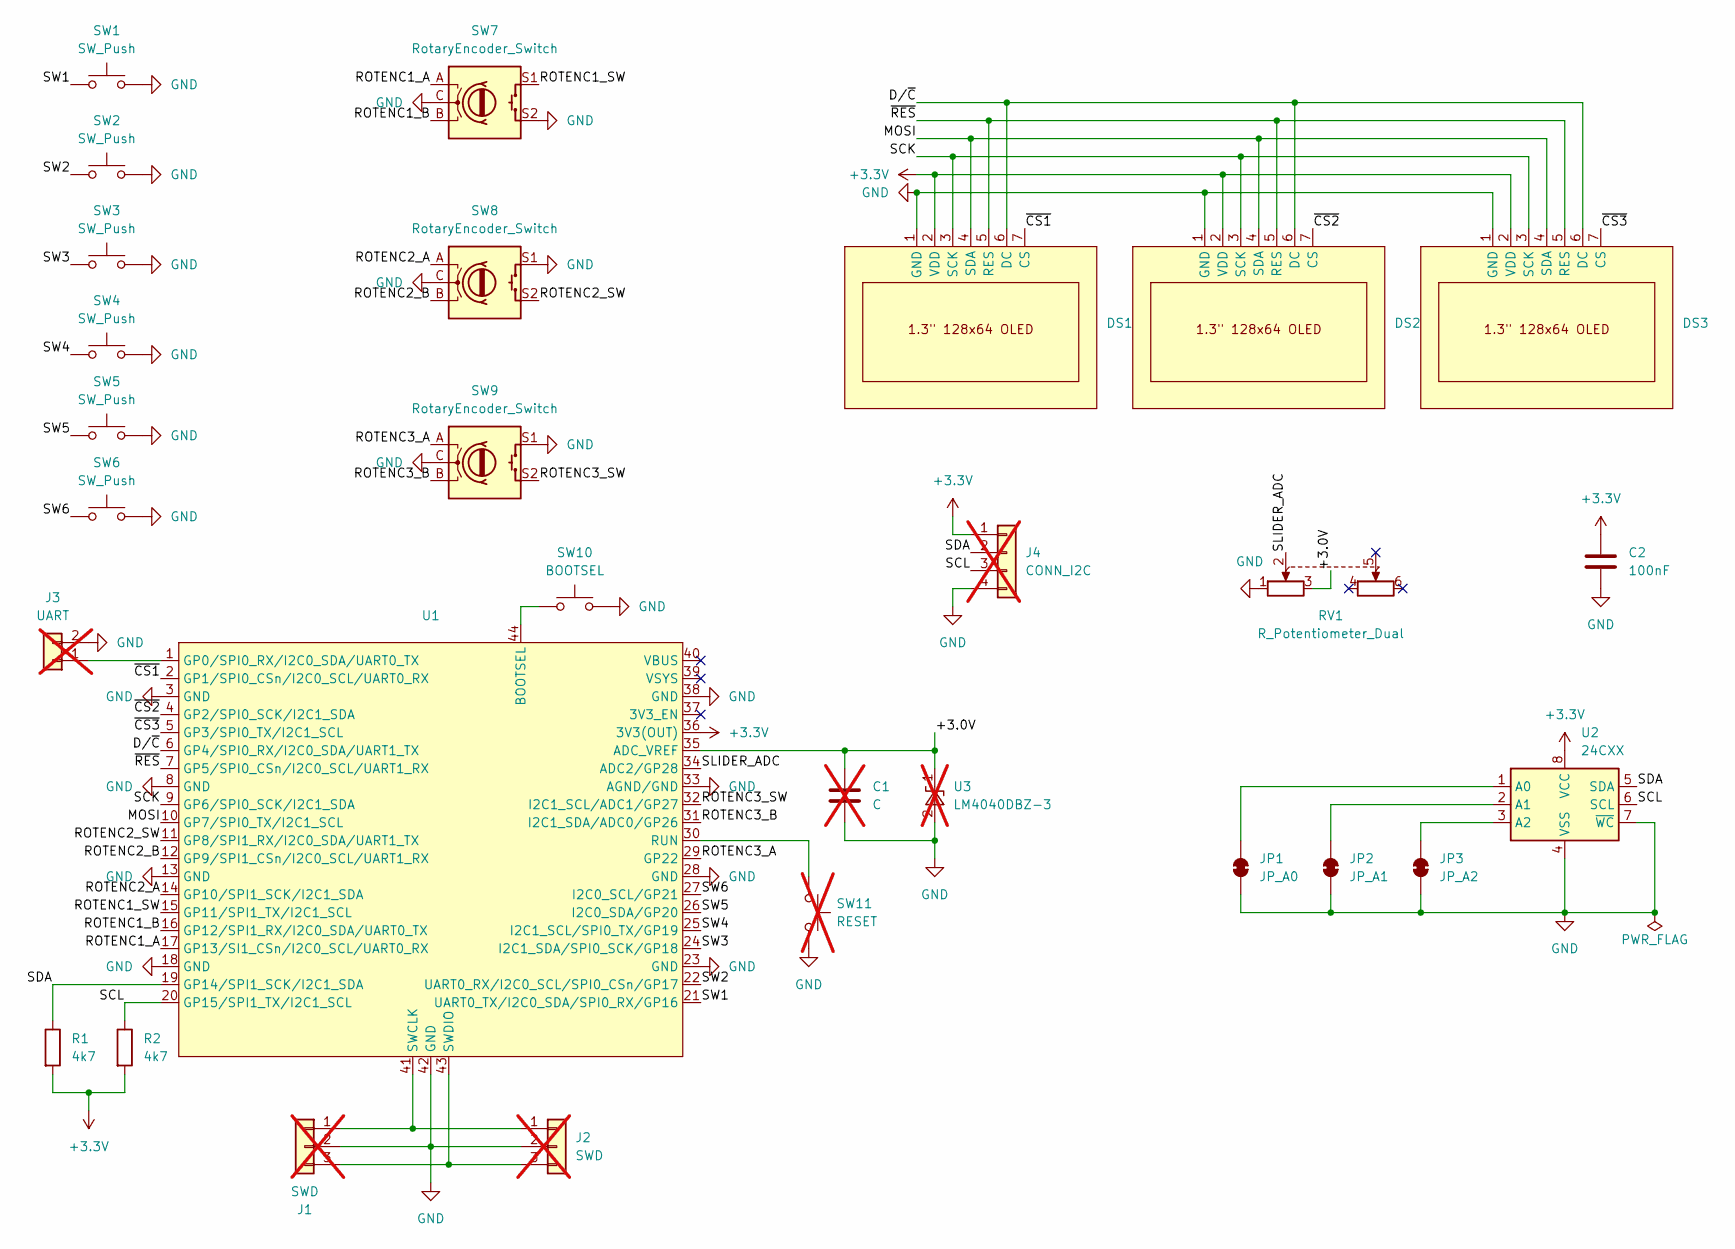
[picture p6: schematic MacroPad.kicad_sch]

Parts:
C1: C; C_1206_3216Metric_Pad1.33x1.80mm_HandSolder; not fitted
C2: 100nF; C_1206_3216Metric_Pad1.33x1.80mm_HandSolder
DS1, DS2, DS3: OLED 1.3in
J1: SWD; PinHeader_1x03_P2.54mm_Horizontal; not fitted
J2: SWD; JST_SH_SM03B-SRSS-TB_1x03-1MP_P1.00mm_Horizontal; not fitted
J3: UART; PinHeader_1x02_P2.54mm_Horizontal; not fitted
J4: CONN_I2C; PinHeader_1x04_P2.54mm_Horizontal; not fitted
JP1: JP_A0; SolderJumper-2_P1.3mm_Bridged_RoundedPad1.0x1.5mm
JP2: JP_A1; SolderJumper-2_P1.3mm_Bridged_RoundedPad1.0x1.5mm
JP3: JP_A2; SolderJumper-2_P1.3mm_Bridged_RoundedPad1.0x1.5mm
R1, R2: 4k7; R_1206_3216Metric_Pad1.30x1.75mm_HandSolder
RV1: R_Potentiometer_Dual; ALPS_RS60112
SW1, SW2, SW3, SW4, SW5, SW6: SW_Push; SW_Cherry_MX_1.00u_PCB
SW7, SW8, SW9: RotaryEncoder_Switch; RotaryEncoder_Alps_EC11E-Switch_Vertical_H20mm
SW10: BOOTSEL; MicroSwitch
SW11: RESET; MicroSwitch; not fitted
U1: RPi_Pico_SMD_TH
U2: 24CXX; SOIC-8_3.9x4.9mm_P1.27mm
U3: LM4040DBZ-3; SOT-23; not fitted

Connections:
+3.3V: C2.1, DS1.2 (VDD), DS2.2 (VDD), DS3.2 (VDD), J4.1, R1.2, R2.2, U1.36 (3V3(OUT)), U2.8 (VCC)
/+3.0V: C1.1, RV1.3, U1.35 (ADC_VREF), U3.1 (K)
/D/~C: DS1.6 (DC), DS2.6 (DC), DS3.6 (DC), U1.6 (GP4/SPI0_RX/I2C0_SDA/UART1_TX)
/MOSI: DS1.4 (SDA), DS2.4 (SDA), DS3.4 (SDA), U1.10 (GP7/SPI0_TX/I2C1_SCL)
/ROTENC1_A: SW7.A, U1.17 (GP13/SI1_CSn/I2C0_SCL/UART0_RX)
/ROTENC1_B: SW7.B, U1.16 (GP12/SPI1_RX/I2C0_SDA/UART0_TX)
/ROTENC1_SW: SW7.S1, U1.15 (GP11/SPI1_TX/I2C1_SCL)
/ROTENC2_A: SW8.A, U1.14 (GP10/SPI1_SCK/I2C1_SDA)
/ROTENC2_B: SW8.B, U1.12 (GP9/SPI1_CSn/I2C0_SCL/UART1_RX)
/ROTENC2_SW: SW8.S2, U1.11 (GP8/SPI1_RX/I2C0_SDA/UART1_TX)
/ROTENC3_A: SW9.A, U1.29 (GP22)
/ROTENC3_B: SW9.B, U1.31 (I2C1_SDA/ADC0/GP26)
/ROTENC3_SW: SW9.S2, U1.32 (I2C1_SCL/ADC1/GP27)
/SCK: DS1.3 (SCK), DS2.3 (SCK), DS3.3 (SCK), U1.9 (GP6/SPI0_SCK/I2C1_SDA)
/SCL: J4.3, R2.1, U1.20 (GP15/SPI1_TX/I2C1_SCL), U2.6 (SCL)
/SDA: J4.2, R1.1, U1.19 (GP14/SPI1_SCK/I2C1_SDA), U2.5 (SDA)
/SLIDER_ADC: RV1.2, U1.34 (ADC2/GP28)
/SW1: SW1.1, U1.21 (UART0_TX/I2C0_SDA/SPI0_RX/GP16)
/SW2: SW2.1, U1.22 (UART0_RX/I2C0_SCL/SPI0_CSn/GP17)
/SW3: SW3.1, U1.24 (I2C1_SDA/SPI0_SCK/GP18)
/SW4: SW4.1, U1.25 (I2C1_SCL/SPI0_TX/GP19)
/SW5: SW5.1, U1.26 (I2C0_SDA/GP20)
/SW6: SW6.1, U1.27 (I2C0_SCL/GP21)
/~CS1: DS1.7 (CS), U1.2 (GP1/SPI0_CSn/I2C0_SCL/UART0_RX)
/~CS2: DS2.7 (CS), U1.4 (GP2/SPI0_SCK/I2C1_SDA)
/~CS3: DS3.7 (CS), U1.5 (GP3/SPI0_TX/I2C1_SCL)
/~RES: DS1.5 (RES), DS2.5 (RES), DS3.5 (RES), U1.7 (GP5/SPI0_CSn/I2C0_SCL/UART1_RX)
GND: C1.2, C2.2, DS1.1 (GND), DS2.1 (GND), DS3.1 (GND), J1.2, J2.2, J3.2, J4.4, JP1.1 (A), JP2.1 (A), JP3.1 (A), RV1.1, SW1.2, SW2.2, SW3.2, SW4.2, SW5.2, SW6.2, SW7.C, SW7.S2, SW8.C, SW8.S1, SW9.C, SW9.S1, SW10.2, SW11.2, U1.3 (GND), U1.8 (GND), U1.13 (GND), U1.18 (GND), U1.23 (GND), U1.28 (GND), U1.33 (AGND/GND), U1.38 (GND), U1.42 (GND), U2.4 (VSS), U2.7 (~WC), U3.2 (A)
unnamed: J1.1, J2.1, U1.41 (SWCLK)
unnamed: J1.3, J2.3, U1.43 (SWDIO)
unnamed: J3.1, U1.1 (GP0/SPI0_RX/I2C0_SDA/UART0_TX)
unnamed: JP1.2 (B), U2.1 (A0)
unnamed: JP2.2 (B), U2.2 (A1)
unnamed: JP3.2 (B), U2.3 (A2)
unnamed: SW10.1, U1.44 (BOOTSEL)
unnamed: SW11.1, U1.30 (RUN)

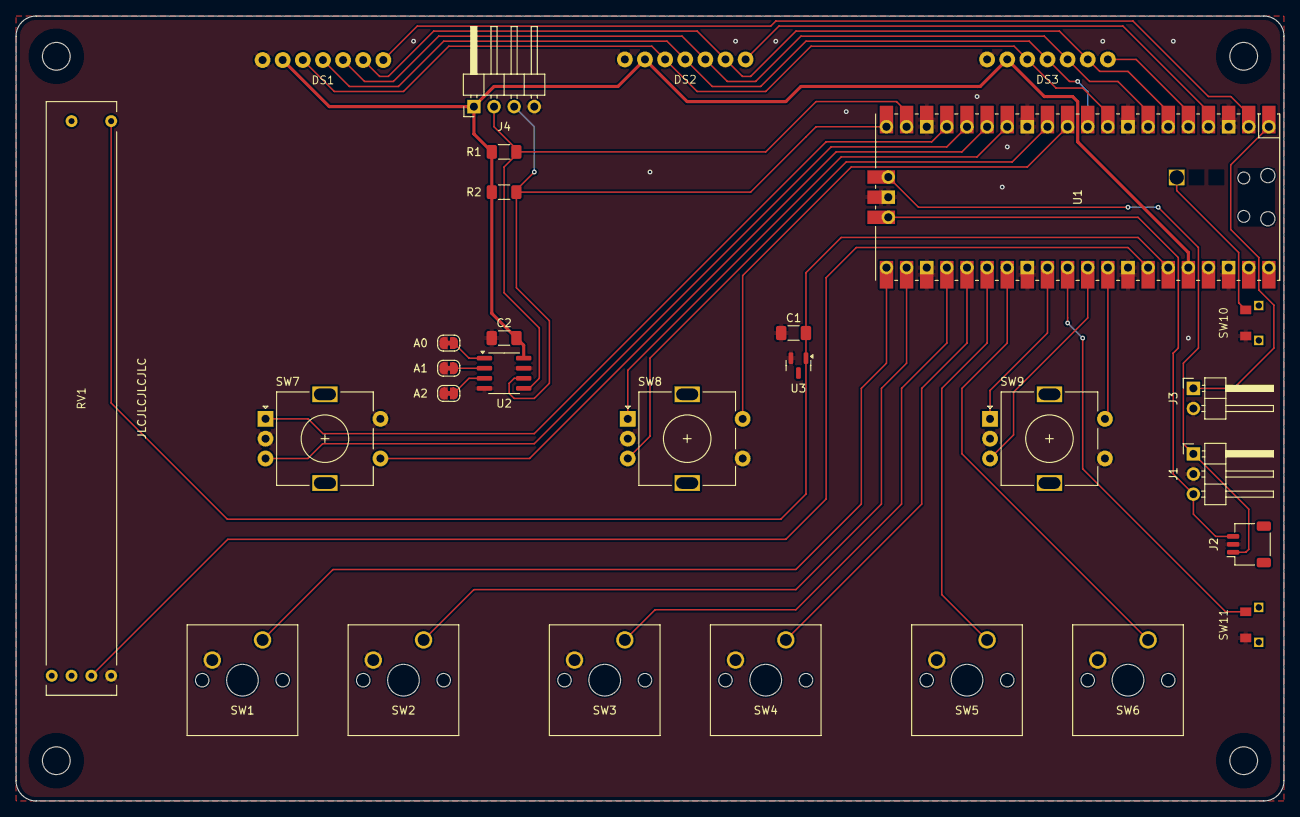
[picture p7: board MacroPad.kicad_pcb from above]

Board: 2 copper layers, 160.0 x 99.1 mm, 29 parts (0 on the bottom side), 36 nets.

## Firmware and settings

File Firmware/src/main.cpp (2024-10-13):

/**
 * \file main.cpp
 */

#include<cstdio>
#include"pico/stdlib.h"
#include"hardware/spi.h"
#include"hardware/i2c.h"
#include "pico/multicore.h"
#include"tusb.h"
#include"usb_descriptors.h"
#include"settings.h"
#include"settingstools.h"
#include"input.h"
#include"eeprom.h"
#include"hid.h"
#include"display.h"

//-----------------------------------------------------------------------------
// Global variables

// Most of these variables are there to communicate status information from
// Core 0 to Core 1. This means they are written by Core 0 and read by Core 1
// which is why they need no synchronisation.

/**
 * \brief Settings
 */
Settings settings;

/**
 * \brief Current operating mode
 * \details This variable is written (and read) by Core 0 and read by Core 1.
 */
static volatile Mode mode = Mode::INITIALISING;

//-----------------------------------------------------------------------------
// Core 1

/**
 * \brief How long (in 50ms units) the turn indicator for a knob should be
 * hightlighted
 */
#define DISPLAY_KNOB_HIGHLIGHT_DURATION 2

/**
 * \brief How long (in 50ms units) the move indicator for the slider should be
 * hightlighted
 */
#define DISPLAY_SLIDER_HIGHLIGHT_DURATION 5

/**
 * \brief How long (in 50ms units) the profile switching indicator should be
 * shown
 */
#define DISPLAY_PROFILE_INDICATOR_DURATION 20

/**
 * \{
 * \brief Background image in normal mode
 */
#include"background_normal.xbm"
// There are five spaces where a 38x30 image can be inserted, one for each of
// the control inputs belonging to a display (knob left/right/push, left/right
// key). These are the (upper left corner) coordinates of these spaces:
#define IMG_ROT_LEFT_X 0
#define IMG_ROT_LEFT_Y 0
#define IMG_ROT_RIGHT_X 90
#define IMG_ROT_RIGHT_Y 0
#define IMG_ROT_PRESS_X 45
#define IMG_ROT_PRESS_Y 11
#define IMG_KEY_LEFT_X 2
#define IMG_KEY_LEFT_Y 32
#define IMG_KEY_RIGHT_X 88
#define IMG_KEY_RIGHT_Y 32
// Mask for the (non-rectangular) highlighted areas
#include"background_mask_knob_press.xbm"
#include"background_mask_key_left.xbm"
#include"background_mask_key_right.xbm"
/// \}

/**
 * \{
 * \brief Background image for slider
 */
#include"background_slider.xbm"
// Images for arrows
#include"arrow_up.xbm"
#include"arrow_down.xbm"
// Position of the progress bar on the slider background
#define IMG_SLIDER_X 48
#define IMG_SLIDER_Y 57
#define IMG_SLIDER_WIDTH 10
#define IMG_SLIDER_HEIGHT 51
#define IMG_ARROW_X 67
#define IMG_ARROW_Y 26
/// \}

/**
 * \{
 * \brief Background image for maintenance mode
 */
#include"background_maintenance.xbm"
/// \}

/**
 * \brief Tells Core 1 which knobs to highlight and for how long
 * \details Set by Core 0, read and decremented by Core 1.
 * For performance reasons, we forego any kind of synchronisation mechanism.
 * Any glitch will be temporary.
 */
static volatile uint8_t displayHighlightKnobs[6] = {0, 0, 0, 0, 0, 0};

/**
 * \brief Tells Core 1 which keys to highlight
 * \details Set and reset by Core 0, read by Core 1.
 */
static volatile bool displayHighlightKeys[9] = {false, false, false, false, false, false, false, false, false};

/**
 * \brief Tells Core 1 whether (and how long) to show the slider indicator
 * \details Set by Core 0, read and decremented by Core 1.
 * For performance reasons, we forego any kind of synchronisation mechanism.
 * Any glitch will be temporary.
 */
uint8_t displaySlider = 0;

/**
 * \{
 * \brief Tells Core 1 what value should be shown for the slider and which
 * direction it was last moved
 * \details Set by Core 0, read by Core 1.
 */
uint displaySliderValue = 0;
int displaySliderDirection = 0;
/// \}

/**
 * \brief Tells Core 1 whether (and how long) to show the profile switch indicator
 * \details Set by Core 0, read and decremented by Core 1.
 * For performance reasons, we forego any kind of synchronisation mechanism.
 * Any glitch will be temporary.
 */
uint8_t displayProfile = 0;

/**
 * \brief Core 1 main function
 * \details Core 1 is responsible for the displays.
 */
void main1()
{
	// Reset all displays (they all share the same reset line on Pin 5)
	gpio_init(5);
	gpio_set_dir(5, true);
	gpio_put(5, 0);
	sleep_ms(200);
	gpio_put(5, 1);
	sleep_ms(100);

	// Initialise spi0 on Pins 6 (SCK) and 7 (MOSI)
	gpio_set_function(6, GPIO_FUNC_SPI);
	gpio_set_function(7, GPIO_FUNC_SPI);
	spi_init(spi0, 2000000);
	spi_set_slave(spi0, false);
	spi_set_format(spi0, 8, SPI_CPOL_0, SPI_CPHA_0, SPI_MSB_FIRST);

	// Initialise displays (CS pins are 1, 2, 3; common DC pin is 4)
	Display displays[3] =
	{
		Display(spi0, 1, 4),
		Display(spi0, 2, 4),
		Display(spi0, 3, 4)
	};
	for(uint i = 0; i < sizeof(displays) / sizeof(Display); i++)
		displays[i].init();

	// Turn displays on
	for(uint i = 0; i < sizeof(displays) / sizeof(Display); i++)
		displays[i].turnOnOff(true);

	// Main loop
	absolute_time_t lastUpdate = from_us_since_boot(0);
	while(1)
	{
		// Sleep during USB suspension
		if(tud_suspended())
		{
			// Turn displays off
			for(uint i = 0; i < sizeof(displays) / sizeof(Display); i++)
				displays[i].turnOnOff(false);
			// Sleep until resumed
			while(tud_suspended())
				__wfe();
			// Turn displays on
			for(uint i = 0; i < sizeof(displays) / sizeof(Display); i++)
				displays[i].turnOnOff(true);
		}
		// Update displays
		absolute_time_t now = get_absolute_time();
		if(absolute_time_diff_us(lastUpdate, now) >= 50000)
		{
			for(uint i = 0; i < sizeof(displays) / sizeof(Display); i++)
				displays[i].fill(0);
			switch(mode)
			{
				case Mode::INITIALISING:
				{
					// Show empty screens
					for(uint i = 0; i < sizeof(displays) / sizeof(Display); i++)
						displays[i].fill(0);
					displays[1].drawText(64, 21, "MacroPad", 0, DEFAULT_FONT, HorizontalAlignment::CENTER, VerticalAlignment::MIDDLE);
					char buf[16];
					snprintf(buf, sizeof(buf), "Version %u.%u", VERSION >> 8, VERSION & 0xff);
					displays[1].drawText(64, 42, buf, 0, DEFAULT_FONT, HorizontalAlignment::CENTER, VerticalAlignment::MIDDLE);
					break;
				}
				case Mode::NORMAL:
				{
					if(displayProfile > 0)
					{
						// Print name and number of profile on left display
						char buf[11];
						snprintf(buf, sizeof(buf), "Profile %u", settings.activeProfile + 1);
						displays[0].drawText(64, 21, buf, 0, DEFAULT_FONT, HorizontalAlignment::CENTER, VerticalAlignment::MIDDLE);
						displays[0].drawText(64, 42, getActiveProfile(settings).name, 0, DEFAULT_FONT, HorizontalAlignment::CENTER, VerticalAlignment::MIDDLE);
						// Show profile picture on middle display
						displays[1].drawBitmap(0, 0, Bitmap<IMG_PROFILE_WIDTH, IMG_PROFILE_HEIGHT>(getActiveProfile(settings).image));
						displayProfile--;
					}
					else
					{
						Bitmap<BKGND_NORMAL_WIDTH, BKGND_NORMAL_HEIGHT> background(BKGND_NORMAL_BITS);
						for(uint i = 0; i < sizeof(displays) / sizeof(Display); i++)
						{
							if(i == 0 && displaySlider > 0) // Display 1 is special b/c of the slider
							{
								displays[i].drawBitmap(0, 0, Bitmap<BACKGROUND_SLIDER_WIDTH, BACKGROUND_SLIDER_HEIGHT>(BACKGROUND_SLIDER_BITS));
								displays[i].drawBitmap(2, 17, Bitmap<IMG_CTRL_WIDTH, IMG_CTRL_HEIGHT>(getActiveProfile(settings).slider.image));
								displays[i].fillRect(IMG_SLIDER_X, IMG_SLIDER_Y, IMG_SLIDER_WIDTH, -(int)displaySliderValue * IMG_SLIDER_HEIGHT / 255, 1);
								if(displaySliderDirection > 0)
									displays[i].drawBitmap(IMG_ARROW_X, IMG_ARROW_Y, Bitmap<ARROW_UP_WIDTH, ARROW_UP_HEIGHT>(ARROW_UP_BITS));
								else if(displaySliderDirection < 0)
									displays[i].drawBitmap(IMG_ARROW_X, IMG_ARROW_Y, Bitmap<ARROW_DOWN_WIDTH, ARROW_DOWN_HEIGHT>(ARROW_DOWN_BITS));
								// Print slider value
								char buf[6];
								snprintf(buf, sizeof(buf), "%u %%", (uint)displaySliderValue * 100 / 255);
								displays[i].drawText(90, 26, buf, 0, DEFAULT_FONT);
								displaySlider--;
							}
							else
							{
								displays[i].drawBitmap(0, 0, background);
								// Left key
								displays[i].drawBitmap(IMG_KEY_LEFT_X, IMG_KEY_LEFT_Y, Bitmap<IMG_CTRL_WIDTH, IMG_CTRL_HEIGHT>((const uint8_t*)getActiveProfile(settings).keys[2 * i].image));
								if(displayHighlightKeys[2 * i])
									displays[i].drawBitmap(0, 0, Bitmap<BACKGROUND_MASK_KEY_LEFT_WIDTH, BACKGROUND_MASK_KEY_LEFT_HEIGHT>(BACKGROUND_MASK_KEY_LEFT_BITS), RasterOperation::XOR);
								// Right key
								displays[i].drawBitmap(IMG_KEY_RIGHT_X, IMG_KEY_RIGHT_Y, Bitmap<IMG_CTRL_WIDTH, IMG_CTRL_HEIGHT>((const uint8_t*)getActiveProfile(settings).keys[2 * i + 1].image));
								if(displayHighlightKeys[2 * i + 1])
									displays[i].drawBitmap(0, 0, Bitmap<BACKGROUND_MASK_KEY_RIGHT_WIDTH, BACKGROUND_MASK_KEY_RIGHT_HEIGHT>(BACKGROUND_MASK_KEY_RIGHT_BITS), RasterOperation::XOR);
								// Knob left
								displays[i].drawBitmap(IMG_ROT_LEFT_X, IMG_ROT_LEFT_Y, Bitmap<IMG_CTRL_WIDTH, IMG_CTRL_HEIGHT>((const uint8_t*)getActiveProfile(settings).knobs[i].imageLeft), displayHighlightKnobs[2 * i] > 0 ? RasterOperation::SRCINV : RasterOperation::SRC);
								// Knob right
								displays[i].drawBitmap(IMG_ROT_RIGHT_X, IMG_ROT_RIGHT_Y, Bitmap<IMG_CTRL_WIDTH, IMG_CTRL_HEIGHT>((const uint8_t*)getActiveProfile(settings).knobs[i].imageRight), displayHighlightKnobs[2 * i + 1] > 0 ? RasterOperation::SRCINV : RasterOperation::SRC);
								// Knob press
								displays[i].drawBitmap(IMG_ROT_PRESS_X, IMG_ROT_PRESS_Y, Bitmap<IMG_CTRL_WIDTH, IMG_CTRL_HEIGHT>((const uint8_t*)getActiveProfile(settings).keys[6 + i].image));
								if(displayHighlightKeys[6 + i])
									displays[i].drawBitmap(0, 0, Bitmap<BACKGROUND_MASK_KNOB_PRESS_WIDTH, BACKGROUND_MASK_KNOB_PRESS_HEIGHT>(BACKGROUND_MASK_KNOB_PRESS_BITS), RasterOperation::XOR);
							}
						}
					}
					for(uint i = 0; i < 6; i++)
						if(displayHighlightKnobs[i] > 0)
							displayHighlightKnobs[i]--;
					break;
				}
				case Mode::MAINTENANCE:
				{
					displays[0].drawText(64, 32, "Maintenance Mode", 0, DEFAULT_FONT, HorizontalAlignment::CENTER, VerticalAlignment::MIDDLE);
					displays[1].drawBitmap(0, 0, Bitmap<BKGND_MAINTENANCE_WIDTH, BKGND_MAINTENANCE_HEIGHT>(BKGND_MAINTENANCE_BITS));
					break;
				}
				case Mode::LOADING_SETTINGS:
				{
					displays[0].drawText(64, 32, "Reading EEPROM", 0, DEFAULT_FONT, HorizontalAlignment::CENTER, VerticalAlignment::MIDDLE);
					displays[1].drawBitmap(0, 0, Bitmap<BKGND_MAINTENANCE_WIDTH, BKGND_MAINTENANCE_HEIGHT>(BKGND_MAINTENANCE_BITS));
					break;
				}
				case Mode::STORING_SETTINGS:
				{
					displays[0].drawText(64, 32, "Writing EEPROM", 0, DEFAULT_FONT, HorizontalAlignment::CENTER, VerticalAlignment::MIDDLE);
					displays[1].drawBitmap(0, 0, Bitmap<BKGND_MAINTENANCE_WIDTH, BKGND_MAINTENANCE_HEIGHT>(BKGND_MAINTENANCE_BITS));
					break;
				}
			}
			for(uint i = 0; i < sizeof(displays) / sizeof(Display); i++)
				displays[i].update();
			lastUpdate = now;
		}
	}
}

//-----------------------------------------------------------------------------
// Core 0

/**
 * \brief EEPROM
 */
EepRom eeprom(i2c1, 400000, EEPROM_24C512);

/**
 * \{
 * \brief Simulated USB devices
 */
UsbHidKeyboard keyboard(ITF_NUM_HID_KEYBOARD);
UsbHidMouse mouse(ITF_NUM_HID_MOUSE);
UsbHidComposite misc(ITF_NUM_HID_MISC);
UsbHidInterface* interfaces[ITF_NUM_TOTAL] = {&keyboard, &mouse, &misc};
/// \}

/**
 * \brief Current address and length for Settings structure
 * \details When in maintenance mode, the host can access the contents of the
 * Settings structure. The address and length determine where within the struct
 * this takes place.
 */
static uint32_t settingsAddress = 0;
static uint8_t settingsLength = sizeof(Settings) < 63 ? sizeof(Settings) : 63;

/**
 * \brief Helper function for profile switching
 * \param profile Index of profile to switch to.
 * \param settings Reference to Settings struct.
 * \param eeprom Reference to EEPROM instance.
 */
void switchProfile(uint8_t profile, Settings& settings, EepRom& eeprom)
{
	// Change settings
	settings.activeProfile = profile;

	// Print message to console
	printf("Switching to profile %u \"%s\"\n", profile + 1, getActiveProfile(settings).name);

	// Make change persistent in EEPROM
	// We're risking a blocking call since it is very little data.
	eeprom.write(&settings.activeProfile, offsetof(Settings, activeProfile), sizeof(settings.activeProfile));

	// Ask Core 1 to display the new profile for a bit
	displayProfile = DISPLAY_PROFILE_INDICATOR_DURATION;
}

/**
 * \brief Core 0 main function
 * \details Core 0 performs all USB-related tasks, most importantly it calls
 * tud_task(). Note that all USB callbacks are invoked from tud_task() which
 * includes answering USB requests on Endpoint 0.
 * It also files umprompted HID reports on the interrupt endpoints.
 */
int main()
{
	// Initialise UART debug output on Pin 0
	stdio_uart_init_full(uart0, 115200, 0, -1);
    printf("\n\n--------------------------------------------------\nStarting...\n");

	// Start Core 1
	multicore_launch_core1(main1);

	// Initialise USB
	tusb_init();
	absolute_time_t lastReportTime = from_us_since_boot(0);

	// Initialise EEPROM
	i2c_init(i2c1, 400000);
	i2c_set_slave_mode(i2c1, false, 0);
	gpio_set_function(14, GPIO_FUNC_I2C);
	gpio_set_function(15, GPIO_FUNC_I2C);
	gpio_pull_up(14);
	gpio_pull_up(15);
	gpio_set_slew_rate(14, GPIO_SLEW_RATE_SLOW);
	gpio_set_slew_rate(15, GPIO_SLEW_RATE_SLOW);
	gpio_set_input_hysteresis_enabled(14, true);
	gpio_set_input_hysteresis_enabled(15, true);
	EepRom::init();

	// Start loading the settings from EEPROM
	mode = Mode::LOADING_SETTINGS;
	eeprom.startReading(reinterpret_cast<uint8_t*>(&settings), 0, sizeof(settings));

	// Initialise InputMonitor
	InputMonitor::create();

	// Main loop
	MacroList activeMacros;
	while(1)
	{
		// 1.) Perform USB tasks
		tud_task();
		if(tud_suspended())
		{
			// Put core to sleep until interrupt or event occurs
			uint32_t status = save_and_disable_interrupts();
			if(!tud_task_event_ready())
				__wfe();
			restore_interrupts(status);
			// Go back to performing USB tasks
			continue;
		}

		// 2.) Perform other tasks
		// These cannot take too long or USB will disconnect.

		// 2.a) Check if we need to wake up the host
		if(tud_suspended() && InputMonitor::getInstance().hasInput())
		{
			printf("Waking up host\n");
			tud_remote_wakeup();
			// Go back to performing USB tasks
			continue;
		}

		// 2.b) Check if settings finished loading/storing
		if(mode == Mode::LOADING_SETTINGS && eeprom.getResult() != EepRom::Result::ONGOING)
		{
			if(eeprom.getResult() != EepRom::Result::SUCCESS || !validateSettings(settings))
			{
				makeDefaultSettings(settings);
				printf("Loading settings failed, using defaults instead\n");
			}
			else
				printf("Settings loaded\n");
			mode = Mode::NORMAL;
		}
		else if(mode == Mode::STORING_SETTINGS && eeprom.getResult() != EepRom::Result::ONGOING)
		{
			if(eeprom.getResult() != EepRom::Result::SUCCESS)
				printf("Storing settings failed\n");
			else
				printf("Settings stored\n");
			mode = Mode::NORMAL;
		}

		// 2.c) Send USB HID reports every 10ms
		absolute_time_t now = get_absolute_time();
		if(mode == Mode::NORMAL && tud_hid_ready() && absolute_time_diff_us(lastReportTime, now) >= 10000)
		{
			// 2.c.i) Go through the event queues of the input controls, start
			// macros, and prepare information for Core 1 to show on the displays

			// Keys: Start macros triggered by events
			for(uint i = 0; i < InputMonitor::getInstance().getNumSwitches(); i++)
			{
				Switch& sw = InputMonitor::getInstance().getSwitch(i);
				while(sw.getEvents().size() > 0)
				{
					Switch::Event event = sw.getEvents().extract();
					const Key& key = getActiveProfile(settings).keys[i];
					const Macro& macro = event.type == Switch::Event::PRESS ? key.press : (event.duration >= key.longPress ? key.longRelease : key.release);
					activeMacros.add(macro);
				}
			}

			// Knobs: Start macros triggered by events and show events on displays
			for(uint i = 0; i < InputMonitor::getInstance().getNumRotaryEncoders(); i++)
			{
				RotaryEncoder& rotenc = InputMonitor::getInstance().getRotaryEncoder(i);
				while(rotenc.getEvents().size() > 0)
				{
					// Get information about event
					RotaryEncoder::Event event = rotenc.getEvents().extract();
					const Knob& knob = getActiveProfile(settings).knobs[i];
					const Macro& macro = event.type == RotaryEncoder::Event::LEFT ? knob.left : knob.right;
					// Start macro
					activeMacros.add(macro);
					// Highlight on display
					if(event.type == RotaryEncoder::Event::LEFT)
						displayHighlightKnobs[2 * i] = DISPLAY_KNOB_HIGHLIGHT_DURATION;
					else
						displayHighlightKnobs[2 * i + 1] = DISPLAY_KNOB_HIGHLIGHT_DURATION;
				}
			}

			// Sliders: Show events on displays
			for(uint i = 0; i < InputMonitor::getInstance().getNumPotentiometers(); i++)
			{
				Potentiometer& poti = InputMonitor::getInstance().getPotentiometer(i);
				while(poti.getEvents().size() > 0)
				{
					Potentiometer::Event event = poti.getEvents().extract();
					displaySlider = DISPLAY_SLIDER_HIGHLIGHT_DURATION;
					displaySliderDirection = event.delta;
					displaySliderValue = event.position;
				}
			}

			// 2.c.ii) Assemble reports
			keyboard.startAssemblingReport();
			mouse.startAssemblingReport();
			misc.startAssemblingReport();
			int switchToProfile = -1;

			// Action due to keys being held down
			for(uint i = 0; i < InputMonitor::getInstance().getNumSwitches(); i++)
			{
				Switch& sw = InputMonitor::getInstance().getSwitch(i);
				if(sw.isPressed())
				{
					// Add action to reports
					const Action& action = getActiveProfile(settings).keys[i].hold;
					if(action.type == ActionType::INPUT)
					{
						keyboard.addActionToReport(getActiveProfile(settings).keys[i].hold);
						mouse.addActionToReport(getActiveProfile(settings).keys[i].hold);
						misc.addActionToReport(getActiveProfile(settings).keys[i].hold);
					}
					else if(action.type == ActionType::SWITCH_PROFILE)
						switchToProfile = action.switchProfile.index;
				}
				// Highlight the switch on the display
				displayHighlightKeys[i] = sw.isPressed();
			}
			// Slider position
			misc.setSlider(InputMonitor::getInstance().getPotentiometer(0).getPosition());
			// Actions from macros that are currently running
			activeMacros.addToReport(interfaces, ITF_NUM_TOTAL, [](const Action& action, void* userData){if(action.type == ActionType::SWITCH_PROFILE) *reinterpret_cast<int*>(userData) = action.switchProfile.index;}, &switchToProfile);

			keyboard.finishAssemblingReport();
			mouse.finishAssemblingReport();
			misc.finishAssemblingReport();

			// 2.c.iii) Send reports
			keyboard.sendReport(0);
			mouse.sendReport(0);
			misc.sendReport(0);

			// 2.c.iv) Check if we encountered a profile-switching action
			if(switchToProfile != -1)
				switchProfile(switchToProfile, settings, eeprom);

			lastReportTime = now;
		}
	}
}

//-----------------------------------------------------------------------------
// USB callbacks

/**
 * \brief Callback for when the device is mounted (which probably means
 * configured)
 */
void tud_mount_cb()
{
	InputMonitor::getInstance().setMode(InputMonitor::Mode::RUNNING);
	printf("USB mounted\n");
}

/**
 * \brief Callback for when the device is unmounted
 */
void tud_umount_cb()
{
	InputMonitor::getInstance().setMode(InputMonitor::Mode::STOPPED);
	printf("USB unmounted\n");
}

/**
 * \brief Callback for when the device is suspended
 * \details The device must draw less than 2.5mA from the bus within 7ms.
 */
void tud_suspend_cb(bool remote_wakeup_en)
{
	InputMonitor::getInstance().setMode(InputMonitor::Mode::SLEEPING);
	printf("USB suspended\n");
}

/**
 * \brief Callback for when the device is resumed (unsuspended)
 */
void tud_resume_cb()
{
	InputMonitor::getInstance().setMode(InputMonitor::Mode::RUNNING);
	printf("USB resumed\n");
}
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

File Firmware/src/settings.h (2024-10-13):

/**
 * \file settings.h
 * Defines the Settings struct, containing the settings for MacroPad.
 * This file is compiled into both the firmware and the settings app.
 */

#ifndef _SETTINGS_H
#define _SETTINGS_H

/// Attribute to make structs tightly packed (this is compiler-dependent)
#define PACKED_STRUCT __attribute__ ((packed))

#include<cstdint>

/**
 * \brief Version number of this software
 * \details The upper byte of this 16-bit unsigned integer contains the major
 * version and the lower byte the minor version (e.g. 0x0104 is v1.4).
 * Both the firmware and the settings app, when generating a Settings struct,
 * write their version number into the attribute. When reading Settings, they
 * check the attribute against their own version.
 * Whenever there is a change in the Settings struct, you need to increment
 * this constant, then re-compile both the firmware and the settings app (both
 * include this header file). Note that changing constants like NUM_PROFILES
 * will also cause Settings struct to change.
 */
#define VERSION 0x0100

/**
 * \brief Key rollover
 * \details Defines how many key presses (not counting modifier keys) can be
 * sent to the host at any one time. Keep in mind that unnecessarily high
 * values will eat up bandwidth on the bus.
 * Note that this only takes effect when report protocol is used. If the host
 * requests boot protocol instead, KRO is fixed at 6.
 */
#ifndef KRO
#define KRO 16
#endif

/**
 * \brief Number of profiles
 * \details Can be changed to accomodate for a larger or smaller EEPROM. The
 * setting take 3 Bytes + NUM_PROFILES * sizeof(Profile), where sizeof(Profile)
 * is currently 6200 Bytes.
 * When NUM_PROFILES is modified, other pieces of code might also need
 * changing, for example makeDefaultSettings().
 */
#define NUM_PROFILES 8

/**
 * \brief Maximum length of the profile name
 * \details Internally, profiles are referred to via an index but towards the
 * user, a textual name is used.
 */
#define MAX_PROFILE_NAME_LEN 32

/**
 * \brief Maximum number of steps in a macro
 */
#define MAX_STEPS_PER_MACRO 4

/**
 * \brief Maximum number of simulanteous keys within an action
 * \details This must not be higher than NKRO, otherwise macros can never
 * be executed.
 */
#define MAX_KEYS_PER_ACTION 6

#if MAX_KEYS_PER_ACTION > KRO
	#error "The maximum number of keys within an Action (MAX_KEYS_PER_ACTION constant) must not exceed KRO."
#endif

/**
 * \{
 * \brief Dimensions of profile images
 */
#define IMG_PROFILE_WIDTH 128
#define IMG_PROFILE_HEIGHT 64
/// \}

/**
 * \{
 * \brief Dimensions of images for input controls (key/knob/slider)
 */
#define IMG_CTRL_WIDTH 38
#define IMG_CTRL_HEIGHT 30
/// \}

/**
 * \{
 * \brief Size of images in bytes
 * \details All images are 1 bit per pixel with rows padded to the next full
 * byte.
 */
#define IMG_SIZE(width, height) ((width) * (((height) + 7) / 8))
#define IMG_PROFILE_SIZE IMG_SIZE(IMG_PROFILE_WIDTH, IMG_PROFILE_HEIGHT)
#define IMG_CTRL_SIZE IMG_SIZE(IMG_CTRL_WIDTH, IMG_CTRL_HEIGHT)
/// \}

/**
 * \brief Determines the type of an Action
 */
enum class ActionType: uint8_t
{
	/// Nothing happens, this is only useful inside macros
	NONE = 0,
	/// Switch to another profile
	SWITCH_PROFILE,
	/// Mouse/keyboard/etc. input
	INPUT
};

/**
 * \brief An Action is a set of inputs that can be sent to the host, like
 * key strokes or mouse movements
 * \details Actions are generated by user inputs - either directy (holding a
 * key down) or indirectly (through a macro). At regular intervals, these
 * actions are collected and compiled into USB HID reports which is then sent
 * to the host.
 * There are also special types of actions concerning profile switching. These
 * are processed locally and do not result in any data being sent to the host.
 */
struct PACKED_STRUCT Action
{
	/**
	 * \brief Type of this Action
	 */
	ActionType type;

	/**
	 * \brief Further information for Actions of type SWITCH_PROFILE
	 */
	struct PACKED_STRUCT
	{
		/**
		 * \brief The index of the profile that should be switched to
		 */
		uint8_t index;
	} switchProfile;

	/**
	 * \brief Further information for Actions of type INPUT
	 */
	struct PACKED_STRUCT
	{
		/**
		 * \brief Status of modifier keys
		 * \details Bits are layed out the same way as defined in the USB
		 * HID specification (c.f. hid_keyboard_modifier_bm_t from TinyUSB):
		 * Bit 0: Left Control
		 * Bit 1: Left Shift
		 * Bit 2: Left Alt
		 * Bit 3: Left Windows
		 * Bit 4: Right Control
		 * Bit 5: Right Shift
		 * Bit 6: Right Alt
		 * Bit 7: Right Windows
		 */
		uint8_t modifiers;

		/**
		 * \brief List of pressed keys
		 * \details The values for the entries are as defined by the USB
		 * HID specification (c.f. the HID_KEY_* constants from TinyUSB).
		 */
		uint8_t keys[MAX_KEYS_PER_ACTION];
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

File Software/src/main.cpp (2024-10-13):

/**
 * \file main.cpp
 * Command line interface (CLI) settings application
 */

#include<iostream>
#include<fstream>
#include<string>
#include<stdexcept>
#include<cstring>
#include<getopt.h>
#include"settings.h"
#include"hid.h"
#include"xmlfile.h"

/**
 * \brief Prints usage information and exits the program
 */
void printUsage()
{
	std::cerr
		<< "MacroPad command line interface (CLI) Settings App" << std::endl
		<< "Version " << (VERSION >> 8) << "." << (VERSION & 0xff) << std::endl
		<< std::endl
		<< "Usage:" << std::endl << std::endl
		<< "macropad-cli --list" << std::endl
		<< "   List all the MacroPad devices connected to this computer." << std::endl << std::endl
		<< "macropad-cli --read <file name> [--device <path>]" << std::endl
		<< "   Read the settings from the MacroPad device with the given device path and save them in the" << std::endl
		<< "   given file." << std::endl << std::endl
		<< "macropad-cli --write <file name> [--device <path>]" << std::endl
		<< "   Load settings from the given file and write them to the MacroPad device with the given device" << std::endl
		<< "   path." << std::endl << std::endl;
	exit(1);
}

/**
 * \brief Command line argument long options
 * \details See getopt_long().
 */
static const struct option longOptions[] =
{
	{"help", no_argument, 0, 'h'},
	{"list", no_argument, 0, 'l'},
	{"read", required_argument, 0, 'r'},
	{"write", required_argument, 0, 'w'},
	{"device", required_argument, 0, 'd'},
	// Secret option for debugging: Instead of reading from/writing to a
	// device, use a binary file instead.
	{"binfile", required_argument, 0, 'b'},
	{0, 0, 0, 0}
};

/**
 * \brief Command line argument (short) options
 * \details See getopt().
 */
static const char* shortOptions = "hlr:w:d:b:";

/**
 * \brief Read settings data from binary file
 * \param filename Name of the file.
 * \return Returns a Settings struct.
 * \throws std::runtime_error If the file is not readable or doesn't contain
 * the correct amount of data.
 */
Settings readFromBinaryFile(std::string filename)
{
	std::ofstream infile(filename, std::ios::binary);
	Settings settings;
	infile.write(reinterpret_cast<char*>(&settings), sizeof(Settings));
	if(!infile.good())
		throw std::runtime_error(std::string("Error reading from binary file: ") + strerror(errno));
	infile.close();
	return settings;
}

/**
 * \brief Write settings data to binary file
 * \param settings Settings to be written to the file.
 * \param filename Name of the file.
 * \throws std::runtime_error If the file cannot be written to.
 */
void writeToBinaryFile(const Settings& settings, std::string filename)
{
	std::ofstream outfile(filename, std::ios::binary);
	outfile.write(reinterpret_cast<const char*>(&settings), sizeof(Settings));
	if(!outfile.good())
		throw std::runtime_error(std::string("Error writing to binary file: ") + strerror(errno));
	outfile.close();
}

/**
 * \brief Main program for command line interface (CLI)
 * \param argc Number of command line arguments (including the command itself).
 * \param argv Array of command line arguments (including the command itself).
 * \return Returns 0 on success or a non-zero value if an error occurs.
 */
int main(int argc, char** argv)
{
	// Print usage if arguments are missing
	if(argc <= 1)
		printUsage();

	// Parse command line arguments
	enum {CMD_HELP, CMD_LIST, CMD_READ, CMD_WRITE} command = CMD_HELP;
	std::string filename, path;
	bool binfileInsteadOfDevice = false;
	int opt, optIdx;
	while((opt = getopt_long(argc, argv, shortOptions, longOptions, &optIdx)) != -1)
	{
		switch(opt)
		{
			case 'h':
				command = CMD_HELP;
				break;
			case 'l':
				command = CMD_LIST;
				break;
			case 'r':
				command = CMD_READ;
				filename = optarg;
				break;
			case 'w':
				command = CMD_WRITE;
				filename = optarg;
				break;
			case 'd':
				path = optarg;
				binfileInsteadOfDevice = false;
				break;
			case 'b':
				path = optarg;
				binfileInsteadOfDevice = true;
				break;
		}
	}

	// Execute the command
	try
	{
		switch(command)
		{
			case CMD_HELP: printUsage(); break;
			case CMD_LIST:
			{
				std::map<std::string, std::string> devices = scanDevices();
				if(devices.empty())
					std::cout << "No MacroPad devices found" << std::endl;
				else
				{
					std::cout << devices.size() << " MacroPad device(s) found:" << std::endl;
					for(const auto& [serial, path] : devices)
						std::cout << "  " << path << " (Serial number " << serial << ")" << std::endl;
				}
				break;
			}
			case CMD_READ:
			{
				Settings settings = binfileInsteadOfDevice ? readFromBinaryFile(path) : readFromDevice(path);
				saveToFile(settings, filename);
				break;
			}
			case CMD_WRITE:
			{
				Settings settings = loadFromFile(filename);
				if(binfileInsteadOfDevice)
					writeToBinaryFile(settings, path);
				else
					writeToDevice(settings, path);
				break;
			}
		}
	}
	catch(const std::runtime_error& e)
	{
		std::cerr << "An error occurred: " << e.what() << std::endl;
		return 1;
	}

	return 0;
}
